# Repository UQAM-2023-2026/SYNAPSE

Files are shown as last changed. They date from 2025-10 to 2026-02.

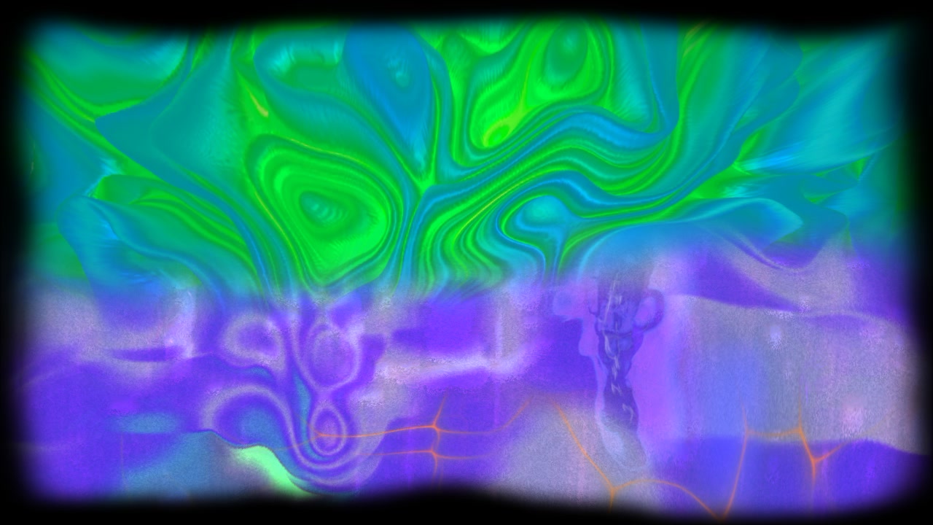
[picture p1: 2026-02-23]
src/TouchDesigner/Supra_Infra/Patch_global/infrasupra.jpeg

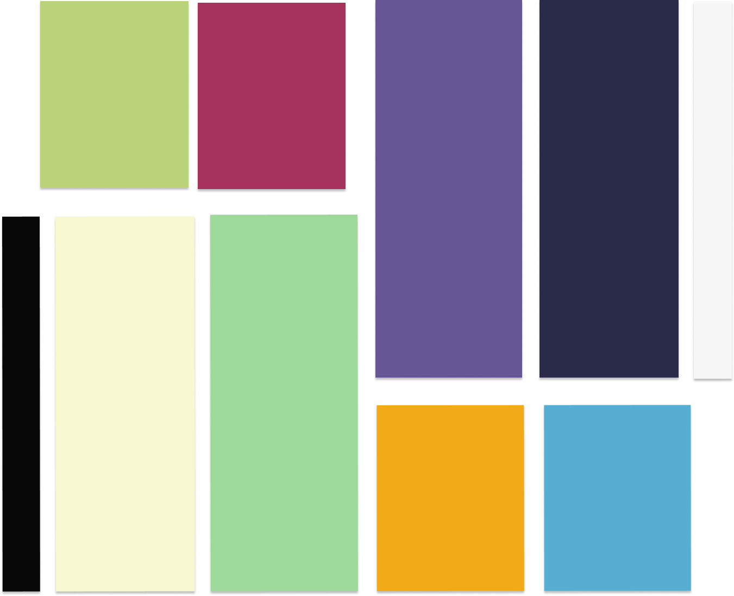
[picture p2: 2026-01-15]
src/TouchDesigner/Supra_Infra/Patch_global/medias/SUPRA/Supra/medias/palette_couleur.webp

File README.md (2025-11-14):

# SYN/APSE  
**Cohorte UQAM Médias Interactifs 2023-2026**

> _Explorer un écosystème du futur, où chaque geste humain nourrit un réseau vivant et lumineux._  

---

## 🌿 Introduction  

**SYN/APSE** est une installation interactive et collective qui invite le public à explorer un écosystème symbiotique inspiré des **réseaux mycorhiziens** — ces structures souterraines où racines et champignons échangent énergie et informations.  

L’œuvre se déploie en deux niveaux — **la Canopée (haut)** et **le Mycélium (bas)** — où les participant·es interagissent à l’aide d’**objets-racines** connectés.  
Chaque geste contribue à la **“communergie”** : un flux d’énergie collective qui illumine, transforme et fait croître un monde partagé.  

SYN/APSE explore les notions de **collaboration, équilibre écologique, espoir et futurité**, à travers une approche **low-tech, écologique et sensible** mêlant art, biologie, design et technologie interactive.

---

## 🧩 Concept et expérience  

### Gestes fondamentaux  
- **Récolter** — capter l’énergie à travers l’exploration et la présence.  
- **Transférer** — échanger cette énergie entre personnes ou systèmes.  
- **Déposer** — redonner à l’écosystème pour le nourrir collectivement.  

### Parcours utilisateur  
1. **Entrée dans la Canopée** : un espace lumineux et sonore où les racines réagissent à la présence.  
2. **Exploration et recharge** : en manipulant l’objet-racine, le public accumule de l’énergie via la lumière et le mouvement.  
3. **Connexion avec autrui** : deux participant·es peuvent rapprocher leurs racines pour amplifier leur énergie commune.  
4. **Dépôt dans un nœud** : l’énergie récoltée est transférée, activant un effet lumineux et sonore dans l’environnement.  
5. **Propagation** : le réseau s’illumine, des bourgeons apparaissent, les sons se multiplient — le monde se régénère.  

Chaque interaction révèle un cycle de **photosynthèse et d’échange**, symbolisant la coopération plutôt que la compétition.

---

## 💡 Technologies  

| Domaine | Outils et technologies |
|---|---|
| **Interactivité** | Capteurs infrarouges, transducteurs de surface, objets magnétiques connectés |
| **Lumière & projection** | Bandes LED, EL-Wire, projecteurs mapping |
| **Son** | Transducteurs sonores et ambiance évolutive |
| **Vision & capture** | Raspberry Pi, caméras et traitement d’image (OpenCV, scikit-image) |
| **IA & générativité** | Réseaux neuronaux pour formes visuelles et rétroaction sensorielle |
| **Logiciels** | TouchDesigner, Python, MaxMSP, Ableton Live |

> _L’installation combine art génératif, code créatif et dispositifs physiques réemployés, afin de limiter son empreinte écologique._

---

## ⚙️ Structure du dépôt  

```
SYN/APSE/
├─ docs/                      # Documentation projet
│  ├─ onboarding/             # Guides pour nouveaux arrivants
│  ├─ methodology/            # Méthodologie, décisions, RACI, etc.
│  └─ architecture/           # Diagrammes (Mermaid, PNG, PDF)
├─ src/                       # Code source (TouchDesigner, Python, etc.)
│  ├─ touchdesigner/
├─ assets/                    # Images, logos, polices
├─ hardware/                  # Schémas, BOM, STL, DXF, gerbers
├─ data/                      # Données (échantillons) — petites tailles
├─ scripts/                   # Outils dev/ops (build, export, sync)
├─ env/                       # Environnements
│  └─ environment.yml         # (renommer PF.yaml)
└─ README.md

```

---

## 🧠 Objectifs  

- Créer un **écosystème interactif** fondé sur la symbiose et l’équilibre collectif.  
- Favoriser une **expérience poétique et éducative** autour du vivant et du numérique.  
- Expérimenter un **design éthique** : matériaux réutilisés, inclusion, accessibilité.  
- Développer un **projet interdisciplinaire** où artistes, programmeur·euses et designers collaborent sur un même système vivant.  

---

## ♻️ Éthique et durabilité  

- **Réemploi** : priorité au matériel déjà existant.  
- **Accessibilité** : participation ouverte à tous.tes, sans barrière technologique.  
- **Équité et diversité** : représentation inclusive dans le concept et la production.  
- **Écologie** : conception à faible impact, matériaux biodégradables et recyclables.  

---

## 🧑‍🤝‍🧑 Équipe  

**Cohorte Médias Interactifs 2023-2026 – UQAM**  

---

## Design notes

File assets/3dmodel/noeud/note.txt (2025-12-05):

les trou sur le coté sont pour un des led et l'autre pour le recepteur. lui du mileu et pour le support. peuttre devoir le grossir avec la drille blanc sur le grandeur tu trou au milieur mais pour les autre c'Est 3 cm par 3 cm

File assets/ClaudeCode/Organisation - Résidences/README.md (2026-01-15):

# Gestion des Résidences de Création

Application web pour gérer les disponibilités, planifier les résidences de création et faciliter l'organisation à l'école.

## 🚀 Démarrage rapide

### Option 1: Serveur Python (Recommandé pour accès réseau)

```bash
python3 serveur.py
```

Le navigateur s'ouvrira automatiquement à `http://localhost:8000/residences.html`

**Pour accéder depuis d'autres ordinateurs sur le même réseau:**
1. Trouvez l'adresse IP de votre ordinateur:
   - Mac/Linux: `ifconfig` ou `ip addr`
   - Windows: `ipconfig`
2. Les autres peuvent accéder à `http://[VOTRE-IP]:8000/residences.html`

### Option 2: Ouvrir directement le fichier

Double-cliquez simplement sur `residences.html` - ça fonctionne hors ligne!

## 📋 Fonctionnalités

### 1. Tableau de bord
- Voir qui est présent aujourd'hui
- Afficher les projets sur lesquels chacun travaille
- Statistiques rapides

### 2. Disponibilités
- Chaque personne peut marquer ses périodes de disponibilité
- Ajouter des notes et des plages horaires spécifiques
- Voir toutes ses disponibilités enregistrées

### 3. Calendrier
- Vue hebdomadaire des disponibilités
- Voir rapidement qui est disponible chaque jour
- Navigation facile entre les semaines

### 4. Résidences
- Planifier une résidence pour une date spécifique
- Sélectionner les personnes qui devraient venir
- Définir un ordre de priorité (qui est prioritaire pour venir)
- Voir toutes les résidences planifiées

### 5. Gestion des personnes
- Ajouter/supprimer des personnes
- Exporter toutes les données en JSON
- Importer des données sauvegardées

## 💾 Sauvegarde des données

Les données sont automatiquement sauvegardées dans le **localStorage** du navigateur.

⚠️ **Important:** Les données sont stockées localement sur chaque ordinateur/navigateur. Pour partager les données entre plusieurs appareils:

1. Utilisez l'option **"Exporter les données"** dans l'onglet "Personnes"
2. Partagez le fichier JSON
3. Importez-le sur les autres appareils

### Pour une utilisation collaborative

Si vous voulez que tout le monde travaille sur les mêmes données en temps réel, vous avez deux options:

#### Option A: Ordinateur partagé à l'école
- Installez l'application sur un ordinateur fixe
- Tout le monde l'utilise sur place

#### Option B: Serveur accessible en ligne
- Hébergez le fichier sur un serveur web
- Utilisez Tailscale, ngrok ou un hébergement cloud
- Tout le monde peut y accéder à distance

## 🎨 Personnalisation

Le fichier `residences.html` est autonome - tout le CSS et JavaScript est inclus. Vous pouvez:
- Modifier les couleurs dans la section `<style>`
- Ajouter des champs personnalisés dans le JavaScript
- Adapter l'interface à vos besoins

## 🔧 Workflow recommandé

1. **En début de session:**
   - Chaque personne marque ses disponibilités dans l'onglet "Disponibilités"

2. **Planification:**
   - L'organisateur va dans "Résidences"
   - Crée une résidence pour une date
   - Sélectionne les personnes (en ordre de priorité)

3. **Jour de résidence:**
   - Ouvrir le "Tableau de bord"
   - Sélectionner la date du jour
   - Voir qui doit venir et sur quoi chacun travaille
   - Mettre à jour les projets au besoin

4. **Sauvegarde régulière:**
   - Exporter les données régulièrement
   - Garder une copie de backup

## 📱 Utilisation mobile

L'interface est responsive et fonctionne sur mobile/tablette!

## 🆘 Support

Pour des questions ou des améliorations, modifiez directement le code HTML ou contactez le développeur.

## 📊 Liste des personnes initiales

L'application est pré-configurée avec les 28 personnes de votre fichier Excel:

Sasha, Dom, Rachel, Florence, Tom, Aldric, Émilie, Maria, Maude, Noum, Med, Thierry, No, JC, Justin, Raton, Anthonny, Sarah, Ugo, Clément, Max, Mery, Laura, Emmanuel, Alexandre, Katianna, Louis-David, Léa

Vous pouvez ajouter ou supprimer des personnes dans l'onglet "Personnes".

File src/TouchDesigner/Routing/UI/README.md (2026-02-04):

# SYNAPSE OSC UI Monitor

Interface web pour visualiser en temps réel les données OSC streamées sur le port 6970.

## Installation

1. Installer les dépendances Python:
```bash
pip install -r requirements.txt
```

## Utilisation

1. Démarrer le serveur OSC/WebSocket:
```bash
python3 osc_server.py
```

2. Ouvrir l'interface web dans un navigateur:
```bash
python3 -m http.server 8000
```

3. Naviguer vers: http://10.0.2.245:8000

## Architecture

- **osc_server.py**: Écoute les messages OSC sur le port 6970 et les redistribue via WebSocket
- **index.html**: Interface web qui affiche les messages en temps réel
- Port OSC: 6970 (local)
- Port WebSocket: 8765
- Port HTTP: 8000

## Fonctionnalités

- Visualisation en temps réel des messages OSC
- Statistiques (messages/sec, total, adresses uniques)
- Pause/Resume du flux
- Export des messages en JSON
- Historique des 1000 derniers messages
- Interface moderne avec gradient et animations

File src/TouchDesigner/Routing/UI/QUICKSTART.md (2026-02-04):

# SYNAPSE Dashboard - Quick Start

## 🚀 Launch en Un Click (Méthode Recommandée)

### Option 1 : Double-click sur macOS
Double-cliquez sur le fichier :
```
LAUNCH_SYNAPSE.command
```

### Option 2 : Via Terminal
```bash
cd /Users/cexiistudiom4max/Desktop/SYNAPSE/src/TouchDesigner/Routing/UI
./launch.py
# ou
python3 launch.py
```

**Le launcher fait automatiquement :**
- ✅ Démarre le serveur OSC/WebSocket (port 6970 + 8765)
- ✅ Démarre le serveur HTTP (port 8000)
- ✅ Ouvre le dashboard dans votre navigateur
- ✅ Gère proprement l'arrêt avec Ctrl+C

## 🛑 Arrêt

Appuyez sur `Ctrl+C` dans le terminal pour arrêter **tous** les services proprement.

## 📊 URLs d'Accès

- **Dashboard** : http://localhost:8000/dashboard.html
- **WebSocket** : ws://localhost:8765
- **OSC Port** : 6970 (UDP)

## 🔧 Configuration TouchDesigner

Dans TouchDesigner, configurez votre **OSC Out CHOP** :
- **Network Address** : `127.0.0.1` (local) ou `10.0.2.245` (réseau)
- **Network Port** : `6970`
- **Protocol** : `UDP`
- **Active** : `On`

## 📱 Résolution

Le dashboard est optimisé pour **1280×720 pixels** (sans scroll).

---

## 🧪 Méthode Manuelle (Alternative)

Si vous préférez lancer les composants séparément :

**Terminal 1** - Serveur OSC/WebSocket :
```bash
python3 debug_server.py
```

**Terminal 2** - Serveur HTTP :
```bash
python3 -m http.server 8000
```

**Navigateur** - Ouvrir manuellement :
```
http://localhost:8000/dashboard.html
```

---

## ⚠️ Troubleshooting

### Port 8000 déjà utilisé
```bash
# Trouver le processus
lsof -i :8000

# Tuer le processus
kill -9 <PID>
```

### Port 6970 (OSC) déjà utilisé
```bash
# Trouver le processus
lsof -i :6970

# Tuer le processus
kill -9 <PID>
```

### Serveur ne démarre pas
Vérifiez que les dépendances sont installées :
```bash
pip install -r requirements.txt
```

### TouchDesigner n'envoie rien
- Vérifier que le OSC Out CHOP est **Active**
- Vérifier le port (doit être `6970`)
- Vérifier l'adresse IP
- Regarder les logs dans TouchDesigner

### L'interface web ne se connecte pas
- Vérifier que le serveur OSC/WebSocket tourne
- Ouvrir la console du navigateur (F12) pour voir les erreurs
- Vérifier le status dans le header (doit être "Connected")

### Dashboard ne s'affiche pas correctement
- Utiliser un navigateur moderne (Chrome, Firefox, Safari récent)
- Vérifier la résolution de la fenêtre (1280×720 recommandé)
- Désactiver les extensions de navigateur qui pourraient interférer

---

## 📁 Structure des Fichiers

```
UI/
├── LAUNCH_SYNAPSE.command     ← Double-click pour démarrer (macOS)
├── launch.py                  ← Launcher Python intelligent
├── debug_server.py            ← Serveur OSC/WebSocket
├── dashboard.html             ← Interface web (1280×720)
├── requirements.txt           ← Dépendances Python
├── QUICKSTART.md              ← Guide de démarrage
├── README.md                  ← Documentation
└── TOUCHDESIGNER_CONFIG.md    ← Configuration TouchDesigner
```

## 🎯 Workflow Recommandé

1. **Double-click** sur `LAUNCH_SYNAPSE.command`
2. Attendre que le navigateur s'ouvre automatiquement
3. Vérifier que le status est "Connected" (LED verte)
4. Lancer TouchDesigner et configurer OSC Out
5. Les données devraient apparaître en temps réel
6. `Ctrl+C` dans le terminal pour tout arrêter

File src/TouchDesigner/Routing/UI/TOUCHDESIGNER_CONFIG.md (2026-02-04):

# Configuration TouchDesigner pour OSC

## Configuration OSC Out dans TouchDesigner

Pour envoyer des données vers le moniteur UI, configurez votre OSC Out CHOP:

1. **Network Address**: `10.0.2.245`
2. **Network Port**: `6970`
3. **Protocol**: `UDP`

## Exemple de configuration

```
OSC Out CHOP:
- Active: On
- Network Address: 10.0.2.245
- Network Port: 6970
- Protocol: UDP
- OSC Address: /synapse/[nom_du_canal]
```

## Test depuis TouchDesigner

Vous pouvez tester en créant un simple setup:

1. Créer un **Constant CHOP** avec quelques canaux
2. Créer un **OSC Out CHOP**
3. Connecter le Constant au OSC Out
4. Configurer l'OSC Out:
   - Address: 10.0.2.245
   - Port: 6970
   - Vérifier que "Active" est coché

## Vérification des ports

Si vous utilisez déjà le port 6970 pour autre chose dans TouchDesigner:

### Option 1: Changer le port du moniteur
Éditez `osc_server.py` ligne 91:
```python
osc_port = 6970  # Changer pour un autre port
```

### Option 2: Changer le port dans TouchDesigner
Modifiez simplement le port dans votre OSC Out CHOP

## Debugging

1. Vérifier que le serveur OSC est lancé:
```bash
lsof -i :6970
```

2. Envoyer des messages de test:
```bash
python3 test_osc.py
```

3. Vérifier les logs du serveur dans le terminal où `osc_server.py` tourne

## Format des messages OSC

Le serveur accepte tous les formats de messages OSC:
- `/chemin/vers/data` [valeur1, valeur2, ...]
- Supporte: float, int, string, bool

Exemple:
- `/synapse/position/x 0.5`
- `/synapse/velocity 1.2 3.4 5.6`
- `/synapse/status "active"`

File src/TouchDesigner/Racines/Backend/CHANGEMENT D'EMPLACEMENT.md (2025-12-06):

La patch de backend a bougé dans src/Touchdesigner/Routing/Backend

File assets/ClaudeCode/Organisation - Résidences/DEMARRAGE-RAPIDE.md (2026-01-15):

# 🚀 Démarrage Rapide - Résidences EDM3003

## Étape 1: Ouvrir l'application

```bash
python3 serveur.py
```

Ou double-cliquez sur `residences.html`

## Étape 2: Importer l'horaire EDM3003

1. Ouvrez `import-horaire.html` dans votre navigateur
2. Cliquez sur **"Importer l'horaire dans l'application"**
3. Cliquez sur **"Ouvrir l'application"**

✅ Toutes les sessions PM/SOIR sont maintenant importées avec leurs types d'activités!

## Étape 3: Marquer les disponibilités

1. Allez dans l'onglet **"Disponibilités"**
2. Cliquez sur votre nom
3. Sélectionnez vos dates de disponibilité
4. Cliquez sur **"Enregistrer la disponibilité"**

## Étape 4: Assigner les personnes aux résidences

1. Allez dans l'onglet **"Résidences"**
2. Trouvez une résidence importée (elles ont une barre colorée à gauche selon le type)
3. Cliquez sur **"Éditer"** *(à implémenter)* ou créez une nouvelle résidence pour une date existante
4. Sélectionnez les personnes qui doivent venir
5. Organisez-les par priorité avec les flèches ↑↓

## Étape 5: Voir qui est là aujourd'hui

1. Allez dans l'onglet **"Tableau de bord"**
2. Sélectionnez la date du jour
3. Voyez toutes les sessions (PM/SOIR) avec:
   - Le type d'activité coloré
   - Les personnes attendues par priorité
   - Les projets sur lesquels chacun travaille

## Types d'activités et couleurs

- 🔵 **Planification** - Bleu
- 🟢 **Résidence de création** - Vert
- 🟡 **Test** - Jaune
- 🔴 **Revue** - Rouge
- 🟣 **Montage** - Violet
- 🟠 **Générale** - Orange
- 🎀 **Lancement** - Rose
- ⚫ **Mise en place / Démontage** - Gris
- 🔵 **Présentation** - Cyan
- 🟢 **Post-mortem** - Teal

## Sessions PM vs SOIR

Les résidences importées ont automatiquement:
- **PM**: 13h00 - 17h00
- **SOIR**: 18h00 - 22h00

Vous pouvez ajuster les heures au besoin.

## Workflow recommandé

### Pour les étudiants:
1. Marquez vos disponibilités à l'avance
2. Consultez le tableau de bord pour voir quand vous êtes attendus
3. Mettez à jour votre projet du jour

### Pour l'organisateur:
1. Importez l'horaire au début de la session
2. Assignez les personnes aux résidences selon les disponibilités
3. Utilisez le système de priorités pour indiquer qui doit absolument venir
4. Consultez le calendrier pour une vue d'ensemble hebdomadaire

## Astuces

- 💾 **Les données sont sauvegardées automatiquement** dans le navigateur
- 📤 **Exportez régulièrement** via l'onglet "Personnes"
- 🎨 **Les couleurs indiquent le type d'activité** - facile de distinguer un test d'une résidence
- 📱 **Fonctionne sur mobile** - consultez le tableau de bord depuis votre téléphone
- 🔍 **Utilisez la recherche** pour trouver rapidement une personne

## Accès réseau (pour toute l'équipe)

Si vous voulez que tout le monde puisse accéder:

1. Lancez le serveur: `python3 serveur.py`
2. Trouvez votre adresse IP:
   - Mac: `ifconfig | grep "inet " | grep -v 127.0.0.1`
   - Linux: `ip addr show | grep "inet " | grep -v 127.0.0.1`
   - Windows: `ipconfig`
3. Les autres accèdent via: `http://[VOTRE-IP]:8000/residences.html`

## Besoin d'aide?

- Consultez le `README.md` pour plus de détails
- Les fichiers sont dans: `/Organisation - Résidences/`
- Vos données sont dans le localStorage du navigateur

## Dates importantes EDM3003

- **12 janv** - Mise en place
- **14 janv** - PLANIFICATION S5
- **26 janv** - TEST INTÉRIEUR 1
- **28 janv** - REVUE S5
- **2 fév** - PLANIFICATION S6
- **11 fév** - TEST INTÉRIEUR 2
- **16 fév** - REVUE S6 (avec public invité!)
- **18 fév** - RÉTRO S6 / PLANIFICATION S7
- **23-25 fév** - Montage Synapse
- **25 fév** - Générale Synapse
- **26 fév - 1 mars** - Lancement Synapse
- **2-5 mars** - Démontage et rangement
- **16 mars** - Post-mortem

Bon courage avec vos résidences! 🎭✨

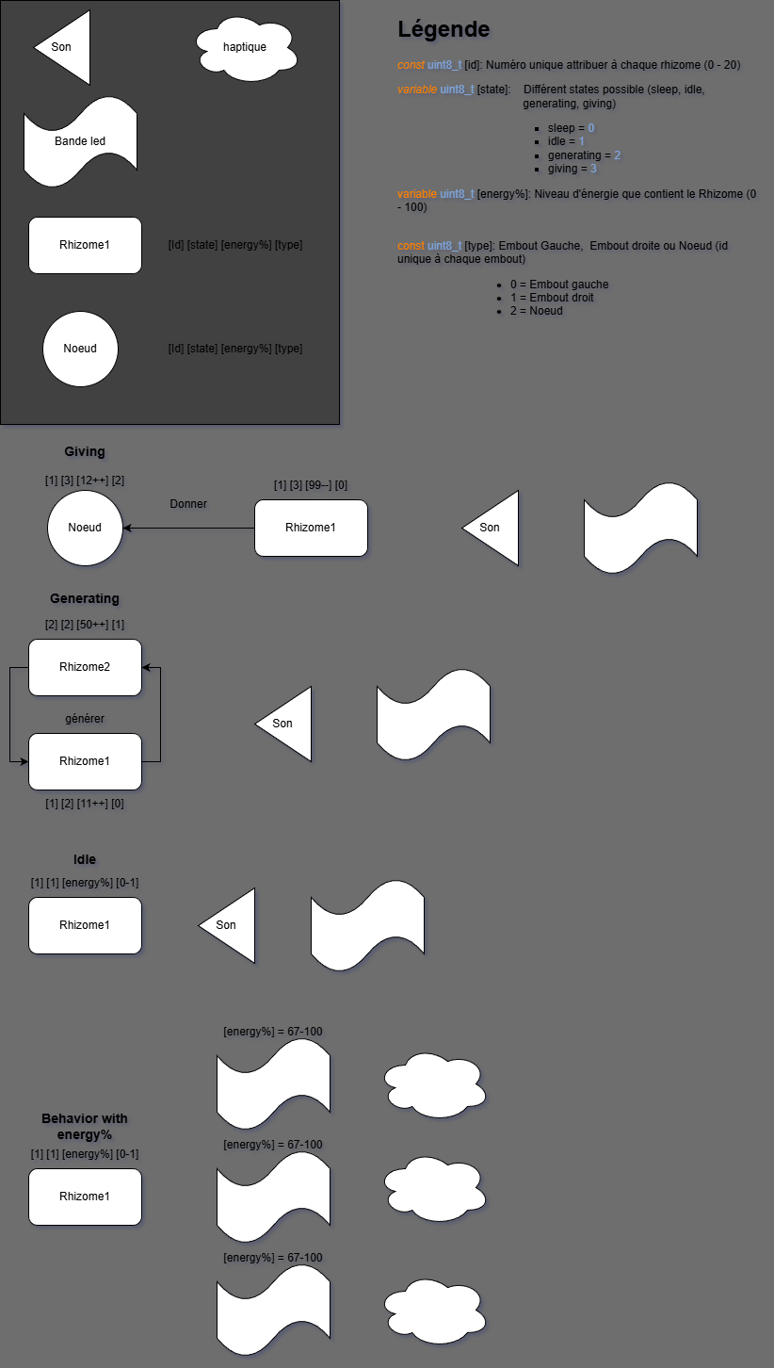
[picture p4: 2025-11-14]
src/schemas/rhizome/KiCad/parcoursEnergie.drawio.png

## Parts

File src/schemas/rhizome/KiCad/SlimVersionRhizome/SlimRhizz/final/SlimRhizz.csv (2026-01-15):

Reference | Value | Footprint
C1,C2,C3 | 1000uf | Capacitor_SMD:CP_Elec_10x10.5
C4,C5 | 100uf | Capacitor_SMD:CP_Elec_6.3x5.4
D1 | PWR | LED_SMD:LED_0402_1005Metric
D2 | HBT | LED_SMD:LED_0402_1005Metric
D3 | L-Connect | LED_SMD:LED_0402_1005Metric
D4 | R-Connect | LED_SMD:LED_0402_1005Metric
J1 | POWER_IN | Connector_JST:JST_XH_B2B-XH-A_1x02_P2.50mm_Vertical
J2 | WS2812_Tip1 | Connector_JST:JST_XH_B3B-XH-A_1x03_P2.50mm_Vertical
J3 | WS2812_Tip2 | Connector_JST:JST_XH_B3B-XH-A_1x03_P2.50mm_Vertical
J4 | APA102_Strip | Connector_JST:JST_XH_B4B-XH-A_1x04_P2.50mm_Vertical
J5 | Haptic_DRV1 | Connector_JST:JST_XH_B4B-XH-A_1x04_P2.50mm_Vertical
J6 | Haptic_DRV2 | Connector_JST:JST_XH_B4B-XH-A_1x04_P2.50mm_Vertical
J7 | Pogo_Male | Connector_JST:JST_XH_B5B-XH-A_1x05_P2.50mm_Vertical
J8 | Pogo_Female | Connector_JST:JST_XH_B5B-XH-A_1x05_P2.50mm_Vertical
R1,R2,R3,R4 | 220 | Resistor_SMD:R_0805_2012Metric
R5 | 1000 | Resistor_SMD:R_0402_1005Metric
R6,R7,R8 | 330 | Resistor_SMD:R_0402_1005Metric

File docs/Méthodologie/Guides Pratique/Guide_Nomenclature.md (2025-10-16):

# Conventions de Nommage (Nomenclature)

La cohérence dans les noms de fichiers est essentielle pour faciliter le travail d’équipe et la maintenance du projet **Mycorhize**.  
Ce guide résume les conventions de nommage définies pour ce projet, en s’alignant sur son vocabulaire thématique (*rhizome*, *nœud*, *supra*, *infra*, *dépôt*, *récolte*, etc.) et sur le ton clair et concis des autres guides d’onboarding.  
L’objectif est de rendre les fichiers aisément identifiables et **rapidement scannables** par tout nouvel arrivant.

---

## Principes Généraux

- **Clarté et concision :** Choisissez des noms de fichiers courts mais explicites.  
  Évitez les termes génériques ou les abréviations obscures.  
  Chaque nom doit indiquer clairement le contenu ou le rôle du fichier (ex. préférez `schema_reseau.png` à `image1.png`).

- **Vocabulaire du projet :** Réutilisez les termes propres à Mycorhize pour refléter la structure du projet.  
  Par exemple :
  - le module central utilise le préfixe **Rhizome** ;
  - les fichiers liés aux capteurs de terrain commencent par **Noeud** ;
  - les éléments de la zone supérieure utilisent **Supra** ;
  - ceux de la zone inférieure utilisent **Infra**.  
  Cette métaphore commune facilite la compréhension du rôle de chaque fichier au sein du « mycélium » du projet.

- **Séparateurs et caractères spéciaux :**  
  N’utilisez **pas d’espaces** ni de caractères accentués dans les noms de fichiers.  
  Remplacez les espaces par des tirets bas `_` et retirez les accents (`Supra` au lieu de `Suprâ`).  
  Évitez les caractères spéciaux et les majuscules dans les extensions.

- **Préfixes par catégorie :**  
  Adoptez un système de **préfixes** pour regrouper les fichiers par type ou fonction :  
  `Rapport_`, `Noeud_`, `Infra_`, `Supra_`, `Rhizome_`, etc.  
  Cela facilite le tri alphabétique et la recherche rapide dans le dépôt.

- **Informations en suffixe :**  
  Ajoutez des détails en fin de nom pour distinguer les versions ou contextes :  
  `_v1`, `_v2`, ou une date au format ISO `AAAA-MM-JJ`.

- **Extensions standard :**  
  Conservez les extensions appropriées (`.pdf`, `.ino`, `.png`, `.wav`, `.mp4`, etc.)  
  sans les répéter dans le nom.

---

## Conventions par Type de Fichier

### Documents PDF (Rapports, Guides, etc.)

- **Nom descriptif + type de doc :**  
  Commencez par un préfixe comme `Rapport_`, `Guide_`, `CompteRendu_`, suivi d’un titre clair.
- **Version et date :**  
  Utilisez un suffixe pour distinguer les versions (`_v2`) ou les dates.
- **Exemples :**
  - `Rapport_Mycorhize_v1.pdf`
  - `Guide_Installation_2025-05.pdf`
  - `Doc_Budget_Supra_2025.pdf`

---

### Code Arduino (Sketches des nœuds et du rhizome)

- **Préfixe du système :**  
  Utilisez **Noeud** pour les capteurs/dispositifs et **Rhizome** pour le module central.  
- **Descriptif fonctionnel :**  
  Ajoutez ensuite la fonction du code (capteurs, transfert, communication…).
- **Exemples :**
  - `Noeud7_CapteursInfra.ino`
  - `Rhizome_TransfertEnergie.ino`
  - `Noeud_Supra_LEDsync_v2.ino`

---

### Fichiers Visuels (Images, Schémas)

- **Contexte et contenu :**  
  Indiquez le module ou la zone (`Supra`, `Infra`, `Noeud`, `Rhizome`) et le contenu (`schema`, `prototype`, `rendu`…).
- **Date ou numéro de version :**  
  Ajoutez une date (`2025-10-16`) ou une version (`v2`).
- **Exemples :**
  - `Infra_Mapping_v1.png`
  - `Schema_Rhizome_v2.svg`
  - `Supra_Installation_2025-10-16.jpg`

---

### Fichiers Audio

- **Source et contexte :**  
  Utilisez un préfixe clair (`Infra`, `Supra`, `NoeudX`, etc.) et un mot-clé décrivant le son.
- **Date d’enregistrement :**  
  Ajoutez la date si plusieurs versions existent.
- **Exemples :**
  - `Audio_Supra_Ambiance_2025-10-16.wav`
  - `Audio_Noed3_Recolte_v1.mp3`
  - `Audio_Infra_Pulse_v2.wav`

---

### Fichiers Vidéo

- **Sujet et emplacement :**  
  Commencez par la zone ou le module (`Infra`, `Supra`, `Rhizome`).
- **Date et séquence :**  
  Ajoutez la date (`AAAA-MM-JJ`) ou un numéro de séquence.
- **Exemples :**
  - `Supra_Timelapse_2025-10-16.mp4`
  - `Infra_Recolte_v2.mp4`
  - `Rhizome_Demo_2025-05-02.mov`

---

## Tableau Récapitulatif des Préfixes/Suffixes

| **Type de fichier** | **Préfixes recommandés** | **Suffixes** |
|---|---|---|
| **Documents PDF** | `Rapport_`, `Guide_`, `Doc_` | `_vX` / date (`AAAA-MM-JJ`) |
| **Code Arduino (.ino)** | `NoeudX_`, `Rhizome_` | *(extension uniquement)* |
| **Visuels (Images)** | `Supra_`, `Infra_`, `NoeudX_`, `Rhizome_` | `_vX` / date (`AAAA-MM-JJ`) |
| **Audio (Sons)** | `Audio_Supra_`, `Audio_Infra_`, `Audio_NoeudX_` | `_vX` / date (`AAAA-MM-JJ`) |
| **Vidéo** | `Supra_`, `Infra_`, `Rhizome_` | `_vX` / date (`AAAA-MM-JJ`) |

---

## Bonnes Pratiques Résumées

✅ Utilisez toujours **des noms en minuscules** et **sans accents**.  
✅ Séparez les mots avec `_`.  
✅ Employez le **vocabulaire du projet** (`rhizome`, `infra`, `supra`, `noeud`).  
✅ Ajoutez une **version ou une date** pour assurer le suivi.  
✅ Soyez **cohérent·e** — le respect collectif de cette nomenclature garantit un dépôt clair et durable.

---

*Fichier : `/docs/onboarding/nomenclature.md`*  
*Version : 1.0 — dernière mise à jour : 2025-10-16*

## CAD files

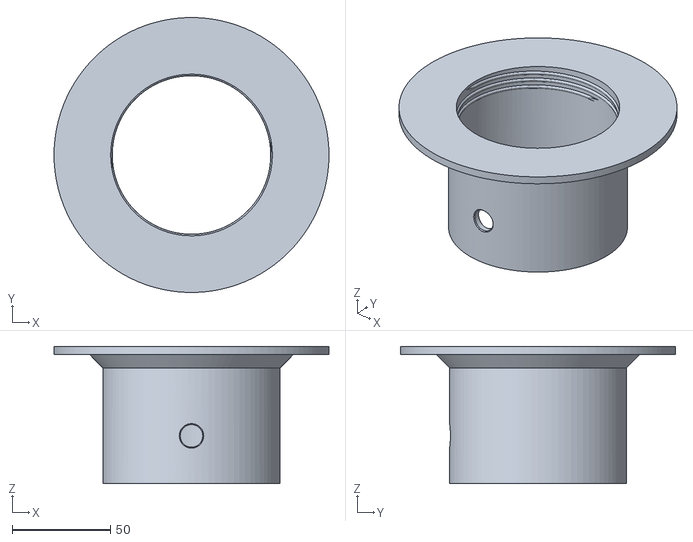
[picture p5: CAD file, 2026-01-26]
assets/3dmodel/noeud/connecteur/Middle_noeu.stl
140.0 x 139.9 x 69.8

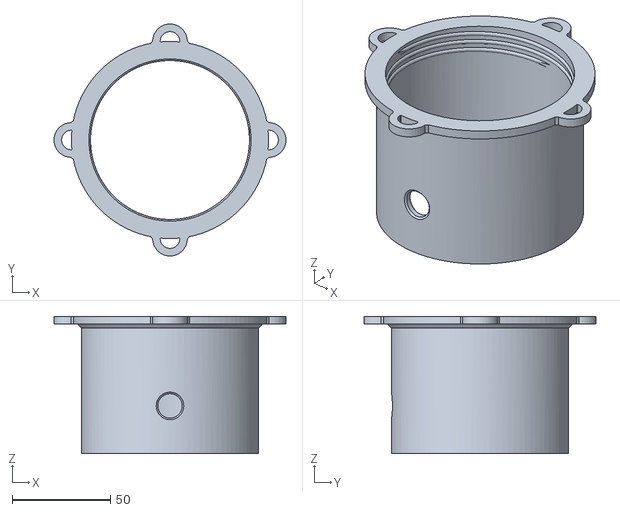
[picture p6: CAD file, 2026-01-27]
assets/3dmodel/noeud/connecteur2/MIDDLE_Connecteur_noeud_v2.stl
117.8 x 117.8 x 69.8

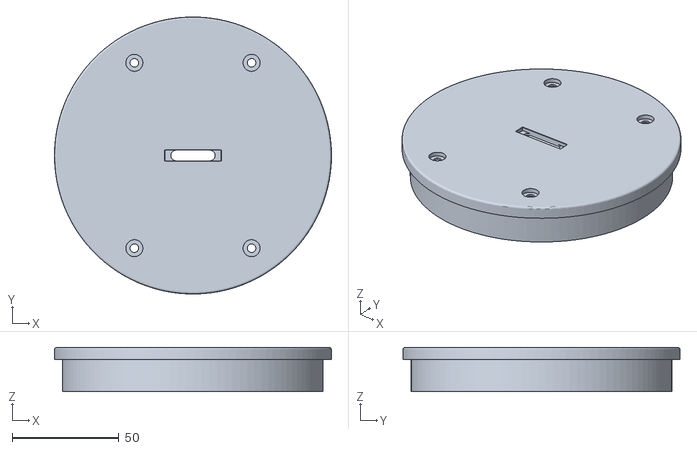
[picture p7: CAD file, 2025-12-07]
assets/3dmodel/noeud/Connecteur_Noeud.stl
130.0 x 130.0 x 20.7

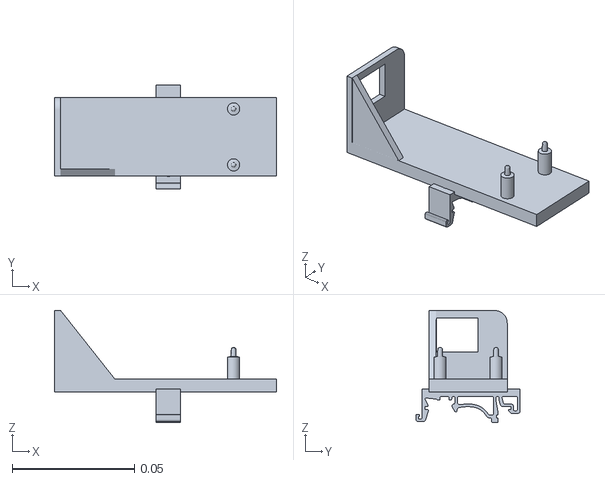
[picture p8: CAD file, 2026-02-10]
assets/3dmodel/noeud/ESPCASE/4espcase.stl
0.0907 x 0.0426 x 0.0458

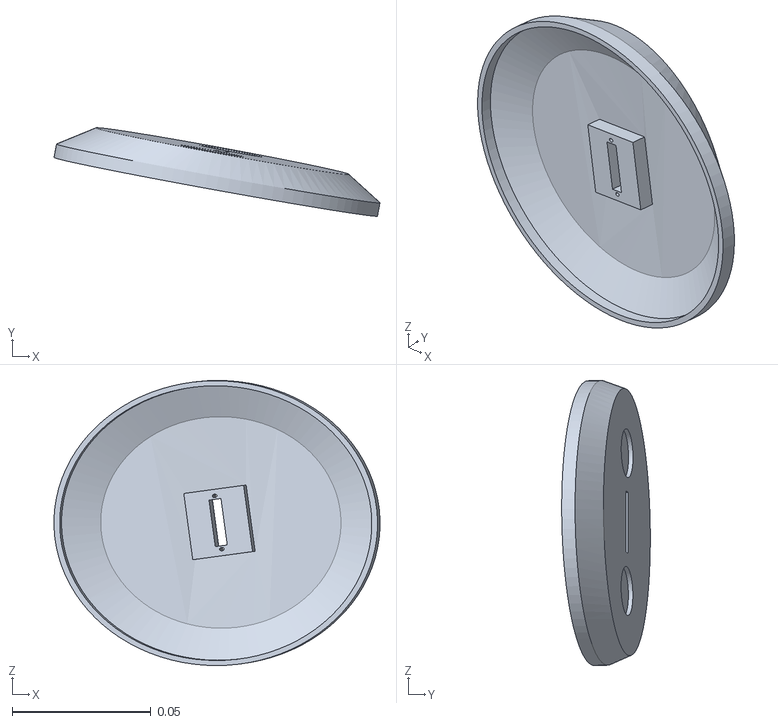
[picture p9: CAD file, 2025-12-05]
assets/3dmodel/obgj/recepeteur- Copie4.obj
0.117 x 0.0319 x 0.103

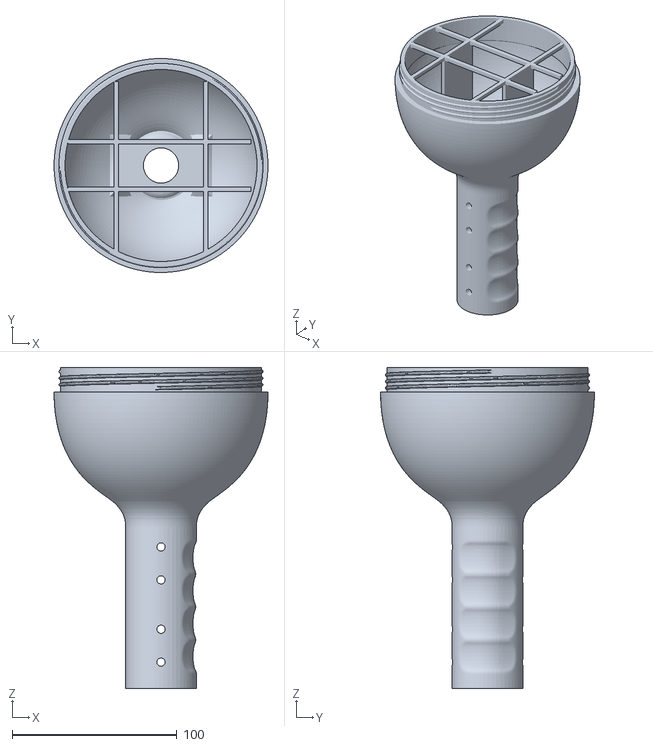
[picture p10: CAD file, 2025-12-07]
assets/3dmodel/Rhizome/v2/Female_plug_RHYZOMME_v2.stl
130.0 x 130.0 x 195.0

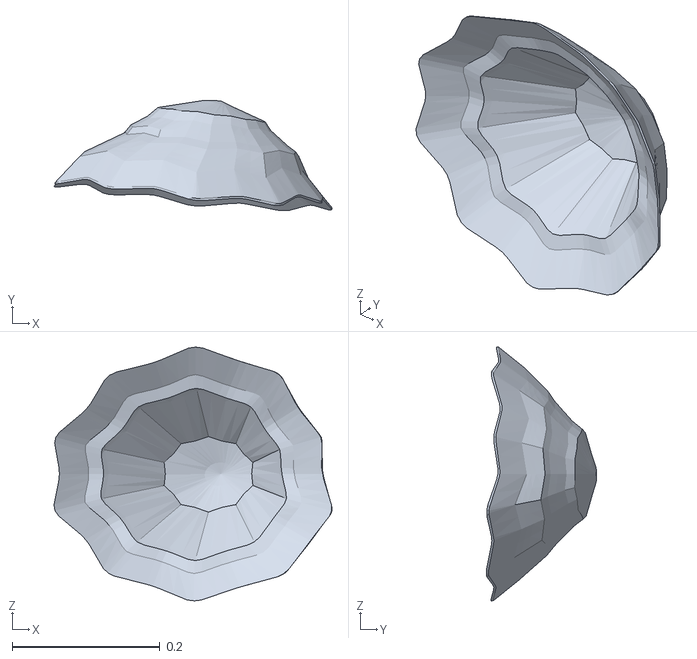
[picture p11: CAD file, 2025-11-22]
assets/3dmodel/testing/Champignon.obj
0.376 x 0.149 x 0.343

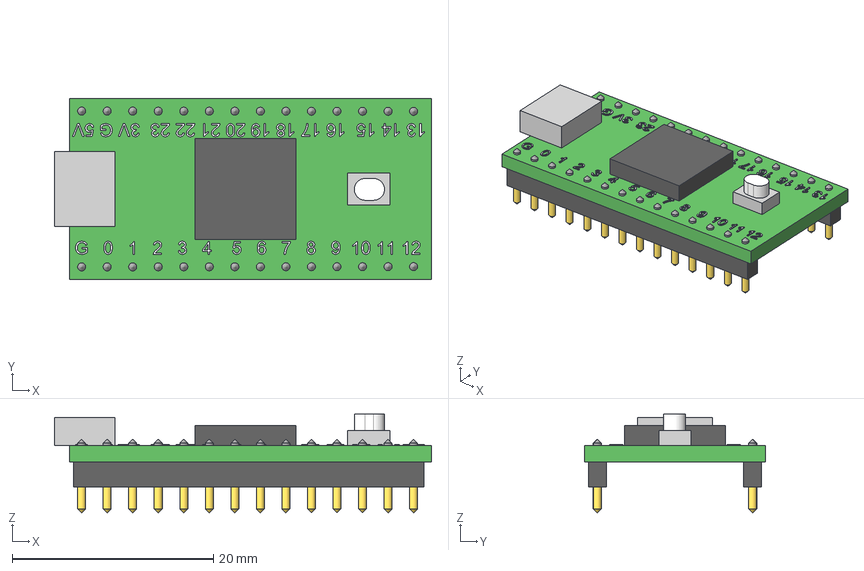
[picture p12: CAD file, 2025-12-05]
src/schemas/rhizome/KiCad/SlimVersionRhizome/SlimRhizz/lib_rhizome/3d_models/Teensy_4.0r0.step
37.5 x 18.0 x 9.80 mm
Teensy_4.0r001

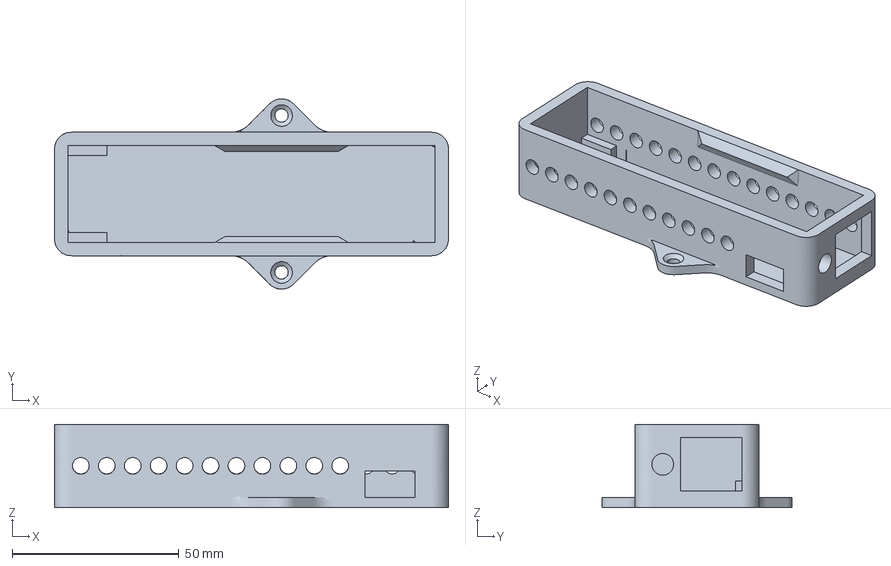
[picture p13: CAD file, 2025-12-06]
assets/3dmodel/noeud/CasePourESP32-POE-ISO.3mf
118.0 x 57.0 x 25.0 mm

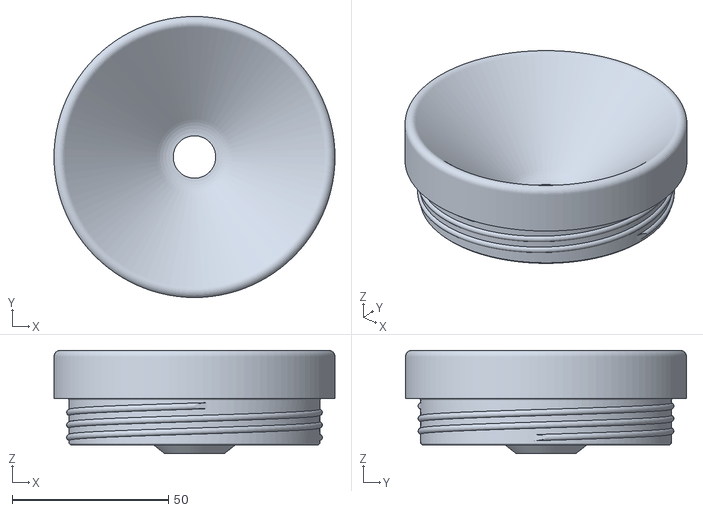
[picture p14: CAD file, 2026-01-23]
assets/3dmodel/noeud/connecteur2/Connecteur_noeu.stl
90.0 x 90.0 x 33.1

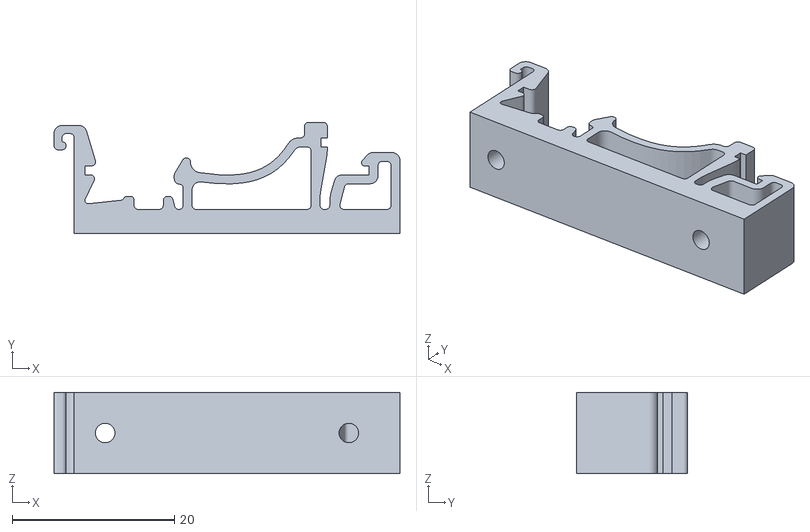
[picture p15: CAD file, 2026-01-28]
assets/3dmodel/noeud/ESPCASE/DIN_holder.stl
42.6 x 13.7 x 10.0

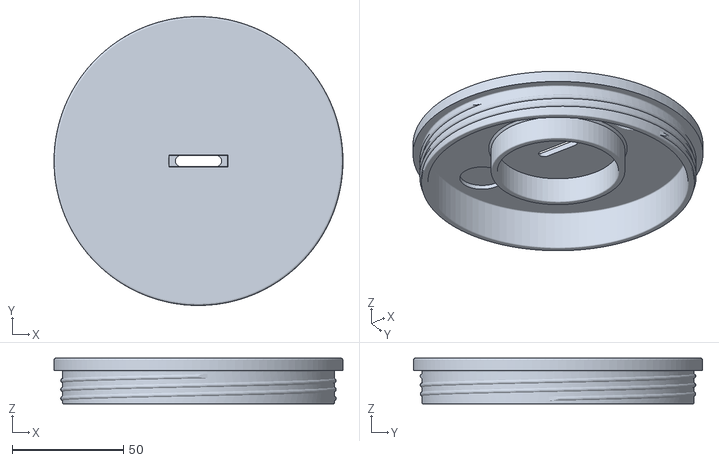
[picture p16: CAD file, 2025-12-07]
assets/3dmodel/Rhizome/v2/Connecteur_rhyzome_v2.stl
130.0 x 130.0 x 20.7

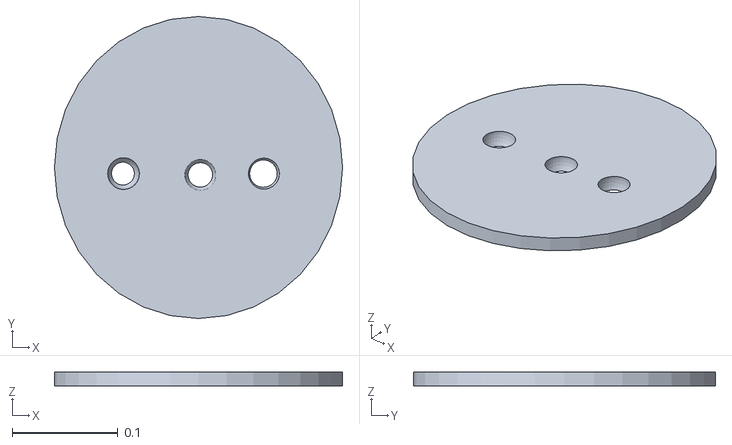
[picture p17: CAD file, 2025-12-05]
assets/3dmodel/noeud/basse- Copie6.stl
0.272 x 0.285 x 0.0134

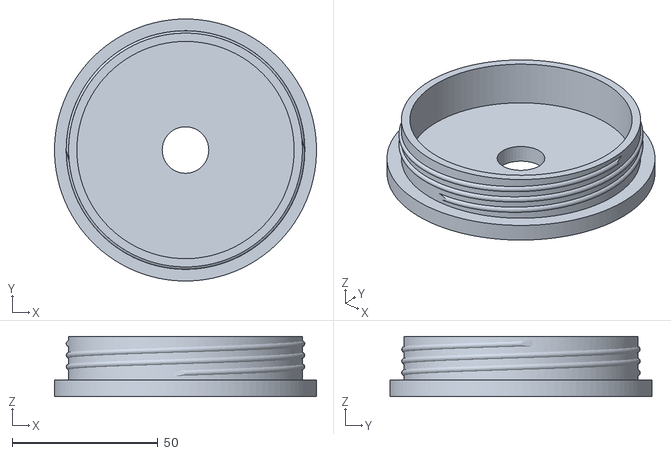
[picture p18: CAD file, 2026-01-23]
assets/3dmodel/noeud/connecteur2/BAse_noeu.stl
90.0 x 90.0 x 20.7

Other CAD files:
assets/3dmodel/noeud/ESPCASE/espcase4.3mf
assets/3dmodel/Rhizome/v2/Middle_V2.stl
assets/3dmodel/noeud/ESPCASE/espbonsens.stl
assets/3dmodel/noeud/ESPCASE/espcase2.stl
assets/3dmodel/Rhizome/v1/Connecteur.stl
assets/3dmodel/Rhizome/v1/Middle.stl
assets/3dmodel/Rhizome/v1/Rhyzome_femelle.stl
assets/3dmodel/Rhizome/v1/Rhyzome_male.stl
assets/3dmodel/VISE.blend
assets/3dmodel/noeud/ESPCASE/4espcase.blend
assets/3dmodel/noeud/ESPCASE/espcase.blend
assets/3dmodel/noeud/ESPCASE/espcase1.stl
assets/3dmodel/noeud/ESPCASE/espcase3.stl
assets/3dmodel/noeud/ESPCASE/espcase4.stl
assets/3dmodel/supportled.blend
assets/3dmodel/testing/CHAMPIGNONblendfinalsanrouge - Copie4.blend
assets/3dmodel/v2- Copie6.blend

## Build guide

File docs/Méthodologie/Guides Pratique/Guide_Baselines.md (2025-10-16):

# Baselines
*Ici, on parle des outils communs qui se retrouveront à travers le projet*

## Outils
### Communication
1. **Discord**
2. **Teams**

### Versionning
1. **Github**
2. *Stockage*

### Workflows
1. **TouchDesigner**
2. **Ableton**
3. **Arduino IDE**
4. **Fritzing**
5. **Diagram.net**
6. **Github Desktop**
7. **Resolume**
9. **DaVinci**
10. **Adobe Suite**

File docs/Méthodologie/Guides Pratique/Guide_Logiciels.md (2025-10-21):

# Guide des versions logicielles
*Ici se trouve les logiciels dont nous avons une ou des licences perpétuelles et leurs versions.*
## TouchDesigner 
Stable **2023.12480**

## Ableton
**Live Suite 11**

## MaxMSP
**Max9**

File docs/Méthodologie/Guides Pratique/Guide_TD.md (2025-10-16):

# Guide d'utilisation TouchDesigner
*ici se trouve les directives concernant la méthodologie de TouchDesigner afin de maximiser le brain-power de tous*

## Nomenclatures
### Patches (*.toe*)
suivre cette nomenclature : 
```

    équipe_NomPatch_versionXY_STATUT_TonNom.toe

```
  où :
  ```

  - *équipe* = Noeud / Rhiz / Supra / Infra / LX / Back / etc

  - *NomPatch* = Nom facile à comprendre qui décrit essentiellement la raison d'être de la patch

  - *versionXY* = numéro de la version, remplacer *X*  en fonction du sprint et *Y* pour la version
            Exemple
                version1a --> version A de la patch au Sprint #1

  - *STATUT* = Statut de la patch [PROD, BUG, REV, GO]
            Où :
              - *PROD* = Production (on going changes)
              - *BUG* = Bug à corriger / non-fonctionnelle
              - *REV* = Peer-review en cours / Prêt à réviser
              - *GO* = Fichier approuvé techniquement et prêt à être déployé

  - TonNom = Ton nom

```
**NE JAMAIS UTILISER DE CHARACTÈRE SPÉCIAUX DANS VOTRE NOMENCLATURE**

### TOX
suivre cette nomenclature :
```

    équipe_FonctionTOX_versionXY_TAG.tox

```
  où :
  ```

  - *équipe* = Noeud / Rhiz / Supra / Infra / LX / Back / etc

  - *FonctionTOX* = Décrit la fonction principale du TOX, simple et concis.

  - *versionXY* = numéro de la version, remplacer *X*  en fonction du sprint et *Y* pour la version
            Exemple
                version1a --> version A de la patch au Sprint #1

  - *TAG* = Catégorie du tox [EFFET, DMX, OSC, TRIGGER, BASE, etc]
            Où :
              - *EFFET* = Visuel
              - *DMX* = Communication DMX
              - *OSC* = Communication OSC
              - *TRIGGER* = Qui trigger un événement
              - *BASE* = TOX de base

```
**NE JAMAIS UTILISER DE CHARACTÈRE SPÉCIAUX DANS VOTRE NOMENCLATURE**
<br>

## Bonnes Pratiques
SVP suivre autant que possible ces consignes, le 2min de plus va nous sauver des heures plus tard.
```

Toujours utiliser un TextDAT à chaque niveau (../) de votre patch qui contient :
  - Explication en détails des éléments
  - Explication de la logique employée
  - Explication des liens entre les données
  - Explication de cette patch dans l'écosystème.
  - Personne Ressource

Toujours utiliser des Null avant d'exporter des données, même si c'est vers un opérateur au même niveau.

Toujours créer des paramètres custom lorsque c'est applicable. Utiliser plusieurs pages de réglages au besoin, en autant que ce soit clair. 
Normaliser la nomenclature des paramêtres.

Utiliser des annotations (SHIFT + A) avec une belle couleur unique bien titré afin de "zoner" les composantes de programmation

Prendre le temps de rendre la patch esthétiquement belle (c'est mieux pour tout le monde)

Utiliser des Select pour éviter les longs branchements laids au besoin

Renommer les opérateurs d'importance et leur attribuer une couleur.

Faire en sorte que n'importe qui peut comprendre la logique et l'emplacement des opérateurs.

```

# Pour tout type de question, parlez à la personne technique de votre équipe ou à Sasha

<br>
<br>

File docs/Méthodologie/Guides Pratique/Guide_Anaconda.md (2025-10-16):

# 🧬 Guide d’utilisation — Anaconda (Projet Mycorhize)

## 🔧 Objectif
Ce guide explique comment :
1. Ouvrir et utiliser **Anaconda**.  
2. Déployer l’environnement existant à partir d’un **backup**.  
3. Installer de nouveaux packages via `pip install`.  
4. Lancer le projet sans modifier la configuration globale.

---

## 🪴 1. Lancer Anaconda

### Sous **Windows**
- Ouvre le **menu Démarrer**.
- Recherche **Anaconda Prompt** et ouvre-le.
- (Optionnel) Tu peux aussi utiliser **Anaconda Navigator** pour une interface graphique.

### Sous **macOS / Linux**
- Ouvre ton **Terminal**.
- Tape :
  ```
  anaconda-navigator
  ```
ou directement :
  ```
  conda activate mycorhize
  ```
🧩 2. Déployer le backup de l’environnement
Un fichier environment_backup.yml (ou environment_backup.txt) est fourni dans le dossier du projet.
C’est une sauvegarde complète de l’environnement Anaconda.

📦 Étapes :
Place le fichier de backup dans ton dossier du projet.

Ouvre Anaconda Prompt ou ton Terminal.

Exécute :
```
conda env create -f environment_backup.yml
```
ou si c’est un fichier .txt :
```
conda create --name mycorhize --file environment_backup.txt
```
Active l’environnement :
```
conda activate mycorhize
```
Vérifie que tout fonctionne :
```
python --version
pip list
```
🧠 3. Ajouter de nouveaux packages
L’environnement contient déjà les dépendances principales.
Si tu veux en ajouter d’autres, utilise pip :
```
pip install numpy
pip install opencv-python
pip install pyserial
```
💡 Astuce : utilise toujours pip (et non conda install) pour rester compatible avec le backup.

Pour vérifier :
```
pip show nom_du_package
```
🧼 4. Mettre à jour les dépendances
Si un nouveau requirements.txt ou environment_backup.yml est publié :
```
pip install -r requirements.txt
```
ou
```
conda env update -f environment_backup.yml --prune
```
🧭 5. Lancer le projet
Depuis l’environnement activé :
```
cd chemin/vers/le/projet
python main.py
```
Exemple :
```
cd "C:\Users\sasha\OneDrive - UQAM\Automne 2025\Projet Final\Mycorhize"
python app.py
```
💾 6. Sauvegarder l’environnement (optionnel)
Si tu fais des modifications importantes :
```
conda env export > environment_backup.yml
```
Cela permet de partager la configuration mise à jour avec toute l’équipe.

⚠️ Erreurs fréquentes
Problème	Solution
CommandNotFoundError: conda	Anaconda n’est pas ajouté au PATH. Ouvre via Anaconda Prompt.
PackagesNotFoundError	Le package n’existe pas dans conda. Utilise pip install.
Environment already exists	Supprime l’ancien avec conda env remove -n mycorhize, puis recrée-le.

🪶 Résumé rapide
Action	Commande
Activer l’environnement	conda activate mycorhize
Installer un package	pip install nom_du_package
Lister les packages	pip list
Mettre à jour depuis backup	conda env update -f environment_backup.yml
Lancer le projet	python main.py

📁 Structure typique du projet
css
Copy code
Mycorhize/
│
├── environment_backup.yml
├── requirements.txt
├── app.py
├── data/
├── src/
└── README.md
✳️ Conseil :
Si tu partages le projet avec d’autres personnes, vérifie que le fichier environment_backup.yml est bien à jour après toute modification des dépendances.

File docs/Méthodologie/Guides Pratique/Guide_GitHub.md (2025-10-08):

# 🌿 Guide GitHub Desktop

### Pour collaborer sur un dépôt existant

(sans créer de branches ni de dépôts)
<br>

## 🛏️ Introduction

GitHub Desktop est une application qui permet de collaborer sur un projet GitHub sans utiliser la ligne de commande. Elle simplifie les actions principales :

#### Pull → récupérer les dernières modifications

#### Commit → sauvegarder vos changements localement

#### Push → envoyer vos changements sur GitHub

#### Merge / Resolve conflicts → fusionner ou corriger les versions différentes
<br>

## 🩴 1. Cloner le dépôt (une seule fois)

#### a) Ouvrir GitHub Desktop

Lancez l’application et connectez-vous à votre compte GitHub.

#### b) Cliquer sur

File → Clone Repository…

#### c) Sélectionner le dépôt du projet

Il apparaîtra dans l’onglet GitHub.com.Cliquez sur Clone.

*💡 Cela crée une copie locale du projet sur votre ordinateur.*

<br>

## 🔄 2. Pull — Mettre à jour votre copie avant de travailler

Avant de modifier un fichier, faites toujours un Pull pour être à jour.

Dans la barre supérieure :➡️ Cliquez sur “Fetch origin”, puis sur “Pull origin” si disponible.

#### 🔸 Fetch = vérifier s’il y a des nouveautés sur GitHub🔸 Pull = télécharger ces nouveautés dans votre copie locale

#### ⚠️ Faites-le chaque fois avant de commencer à travailler.
<br>

## ✏️ 3. Commit — Enregistrer vos changements localement

### Quand vous modifiez ou ajoutez des fichiers dans le dossier du projet :

Revenez dans GitHub DesktopVous verrez la liste des fichiers modifiés dans la colonne de gauche.

Cochez les fichiers que vous voulez enregistrer.

En bas à gauche, écrivez :

*Summary : phrase courte et claire*

(Optionnel) Description plus longue en dessous
<br>

Exemples :

*Ajout du schéma du rhizome*

*Correction du bug d’affichage de la canopée*

*Mise à jour du moodboard*

*Cliquez sur Commit to main.*

#### 💾 Vous venez de créer un commit local, une sauvegarde de vos changements sur votre machine.

<br>

## ☁️ 4. Push — Envoyer vos changements sur GitHub

Une fois votre commit créé, un bouton “Push origin” apparaît en haut.➡️ Cliquez dessus.

**Cela envoie vos modifications sur GitHub pour que toute l’équipe les voie.**

*🧠 Astuce : attendez quelques secondes après un push pour que le dépôt en ligne se mette à jour.*

<br>

## 🔁 5. Merge automatique (Pull avec changements)

Si quelqu’un d’autre a modifié les mêmes fichiers pendant que vous travailliez :

Quand vous cliquerez sur Pull origin, GitHub Desktop essaiera de fusionner (merge) automatiquement.

Si tout se passe bien, un message s’affiche :✅ This branch is up to date with origin/main.

<br>

## ⚠️ 6. Conflits (quand deux versions se contredisent)

Il peut arriver qu’un fichier ait été modifié en même temps par deux personnes.

<br>

**Symptômes :**

*Le pull échoue.*

**Message rouge :“We found some conflicts that need to be resolved.”**

#### Étapes à suivre :

GitHub Desktop vous indique le ou les fichiers en conflit.Cliquez sur “Open in Visual Studio Code” (ou l’éditeur par défaut).

Dans le fichier, vous verrez ceci :
<br>

```
<<<<<<< HEAD
Votre version locale
=======
Version sur GitHub
>>>>>>> main
```
<br>

**Choisissez ce que vous voulez garder, supprimez les lignes inutiles et les marqueurs (<<<<<<<, =======, >>>>>>>).**

**Enregistrez le fichier.**

<br>

**Retournez dans GitHub Desktop :**

**Cochez le fichier résolu.**

<br>

**Écrivez un message de commit commeRésolution du conflit dans fichier.txt.**

<br>

**Cliquez sur Commit merge.**

<br>

**Enfin, cliquez sur Push origin.**

<br>

## 📊 7. Vérifier l’historique

Vous pouvez voir toutes les modifications passées dans l’onglet History :

*Nom de la personne*
<br>
*Message du commit*
<br>
*Fichiers modifiés*
<br>
Très pratique pour comprendre l’évolution du projet.

<br>

## 🤌 Schéma récapitulatif

🚞️ Étapes de base :
<br>
```
    ┌──────────────┐
    │   git pull   │ ←── Télécharge les dernières modifs
    └──────┬───────┘
           │
    ┌──────▼───────┐
    │   git add .  │ ←── Sélectionne les fichiers modifiés
    └──────┬───────┘
           │
    ┌──────▼───────┐
    │ git commit -m│ ←── Enregistre localement les changements
    └──────┬───────┘
           │
    ┌──────▼───────┐
    │   git push   │ ←── Envoie les changements sur GitHub
    └──────────────┘

```
<br>
🔁 Répétez ce cycle chaque fois que vous travaillez sur le projet.
<br>
💡 Bonnes pratiques d’équipe
<br>
✅ Toujours Pull avant de commencer à travailler✅ Commit souvent avec des messages clairs✅ Push dès que possible pour éviter les conflits✅ Si vous voyez un conflit, respirez 😄, puis suivez les étapes ci-dessus✅ Ne supprimez pas de fichiers du projet sans en parler à l’équipe
<br>

## 🛠️ Résumé visuel (terminologie)

<br>

*Pull*

**Récupérer**

**Met à jour votre dossier avec les dernières versions du projet**

<br>

*Commit*

**Sauvegarder localement**

**Enregistre vos modifications sur votre ordinateur**

<br>

*Push*

**Envoyer**

**Met à jour GitHub avec vos commits**

<br>

*Merge*

**Fusionner**

**Combine deux versions différentes d’un fichier**

<br>

*Conflict*

**Désaccord**

**Git vous demande de choisir entre deux versions**

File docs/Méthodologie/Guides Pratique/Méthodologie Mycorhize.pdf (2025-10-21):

# {Mycorhize}

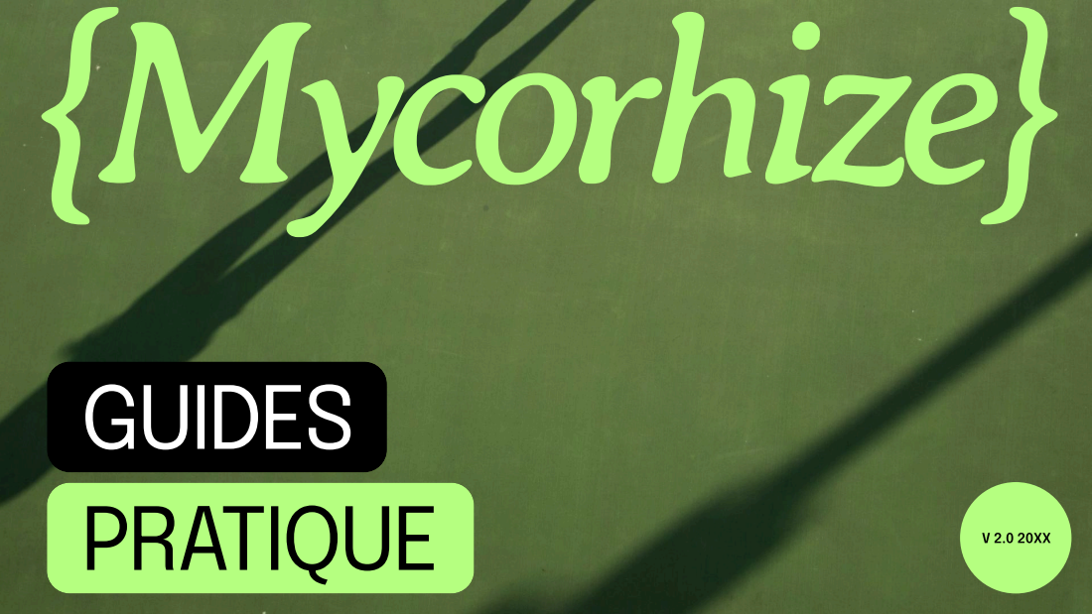
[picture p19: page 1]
Guides; pratique

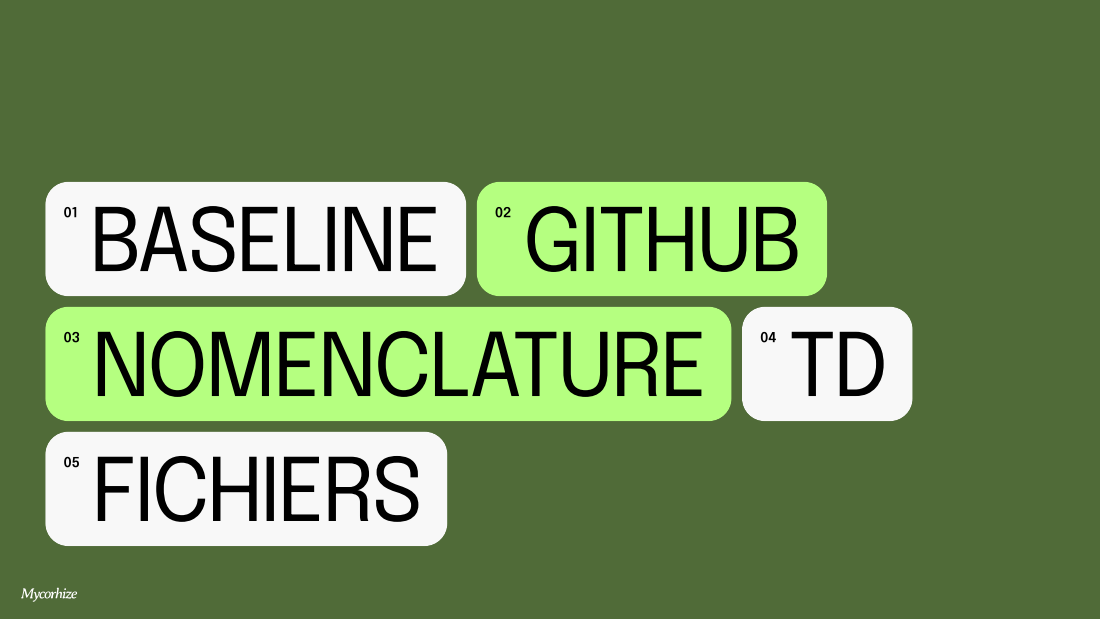
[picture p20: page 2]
Mycorhize; 01Baseline 02Github 03Nomenclature 04; 05 Fichiers

# 01 Guide

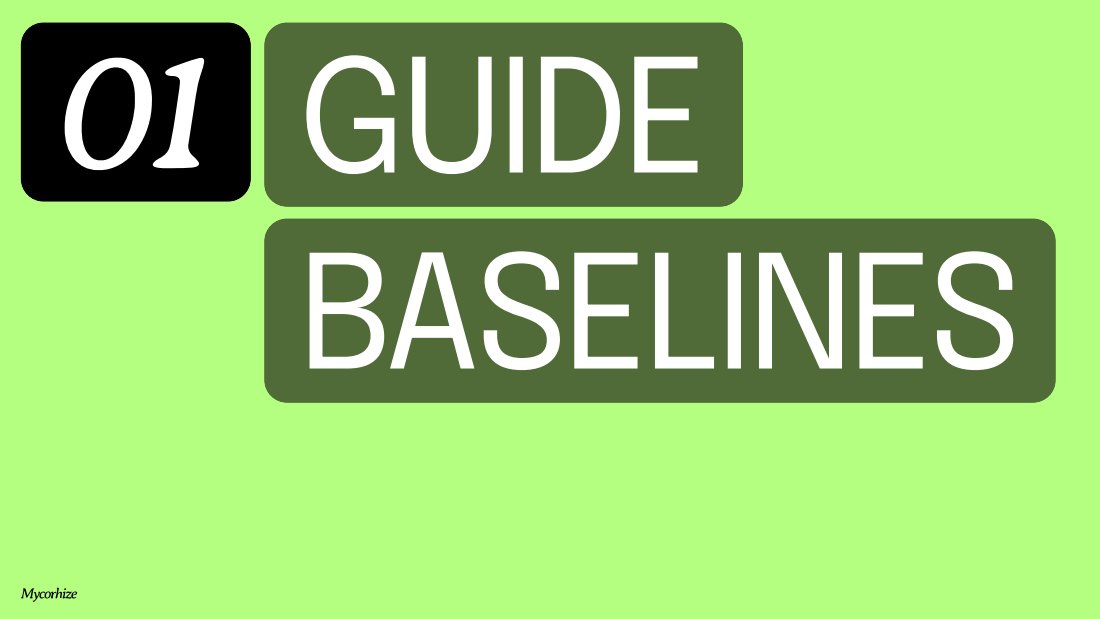
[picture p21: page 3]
Baselines

# Tout projet se doit d’avoir une structure fiable, efficace et adaptée

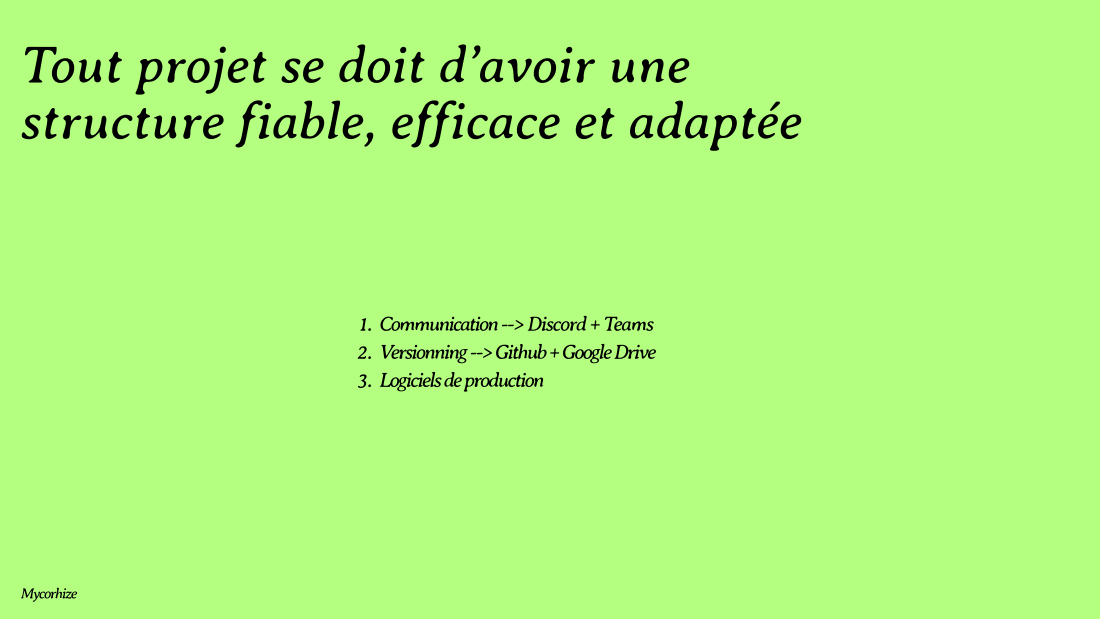
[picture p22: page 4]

Communication --> Discord + Teams
Versionning --> Github + Google Drive
Logiciels de production

# 02 Guide

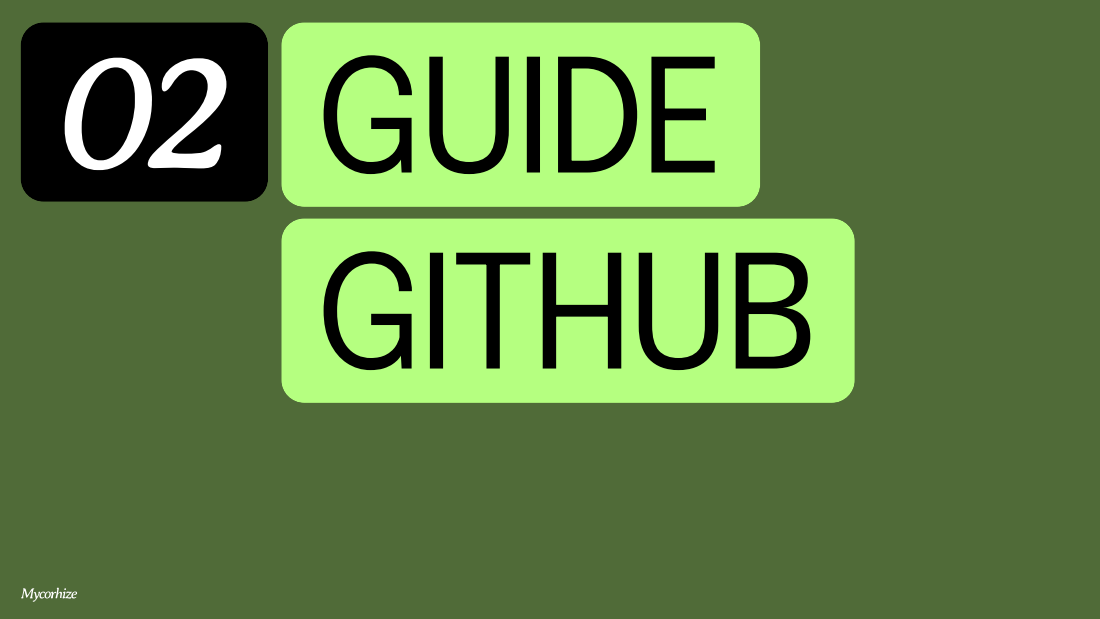
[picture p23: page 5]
Github

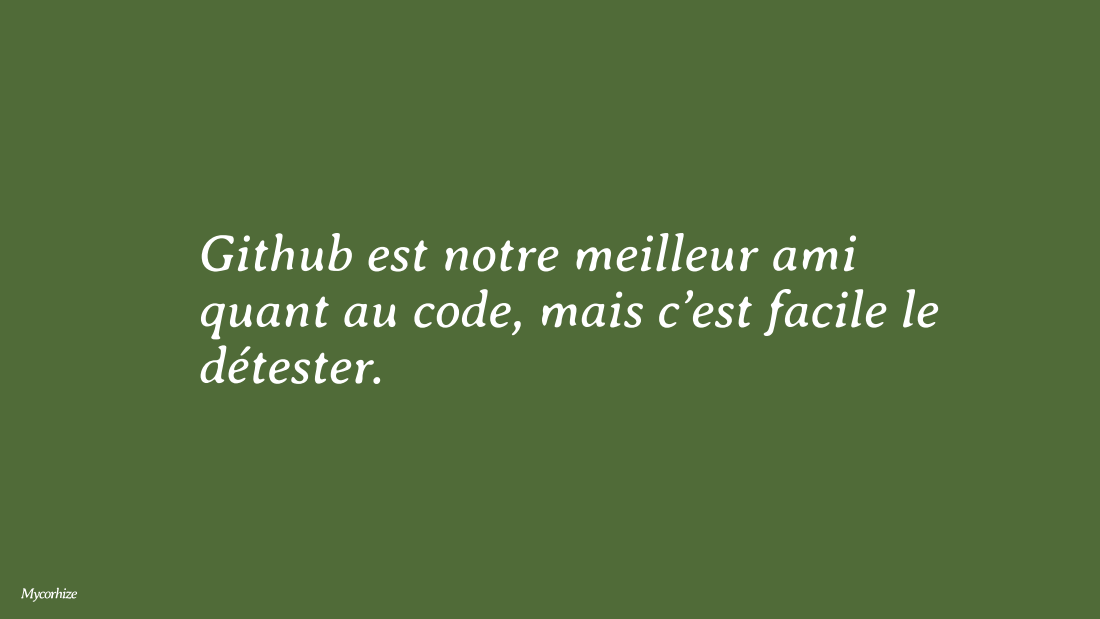
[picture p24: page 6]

Github est notre meilleur ami
quant au code, mais c’est facile le
détester.

# Terminologie

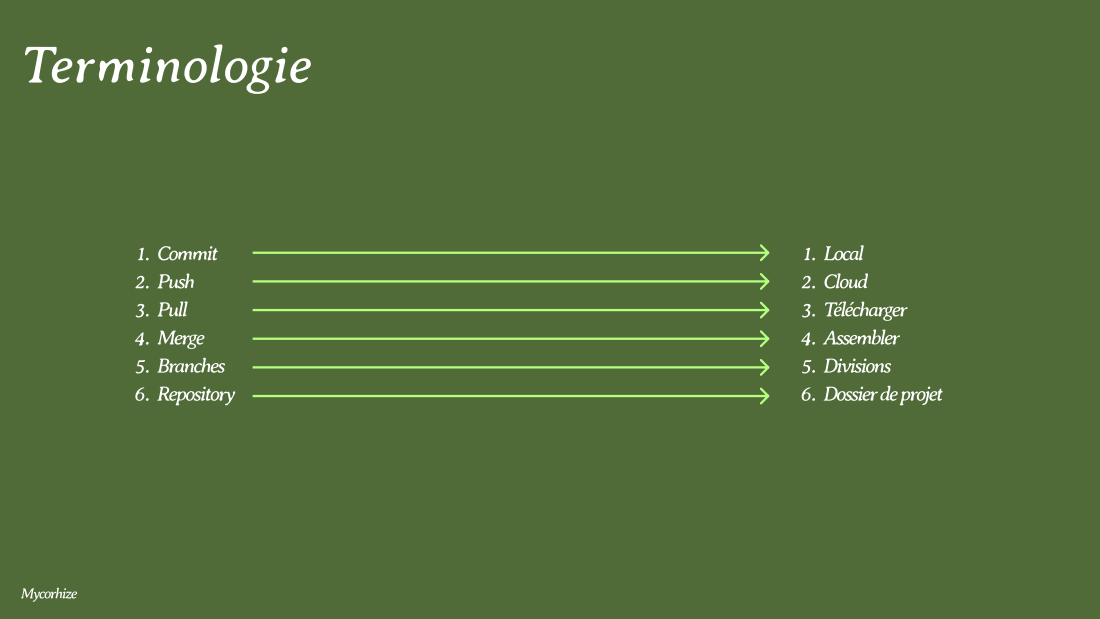
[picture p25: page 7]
Commit; Push Pull; Merge; Branches; Repository; Local Cloud; Télécharger; Assembler; Divisions; Dossier de projet

# Aide-mémoire

Toujours nommer ses commits de façon normalisée, claire et concise Communication entre les membres de la branche pour ne pas avoir de conflits Push ce qui doit être pushed seulement Pull régulièrement Courte description du commit, si nécessaire (mais recommandé) Demander de l’aide pour résoudre les conflits (don’t be a hero si t’es pas sûr.e)

# À faire

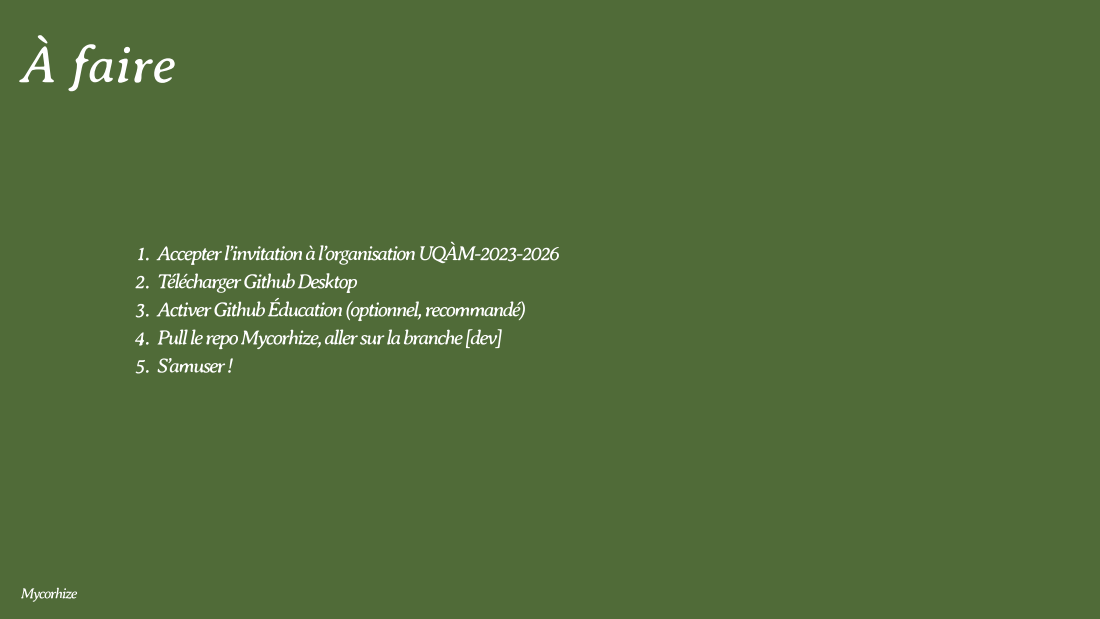
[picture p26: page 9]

Accepter l’invitation à l’organisation UQÀM-2023-2026
Télécharger Github Desktop
Activer Github Éducation (optionnel, recommandé)
Pull le repo Mycorhize, aller sur la branche [dev]
S’amuser !

# 03 Guide

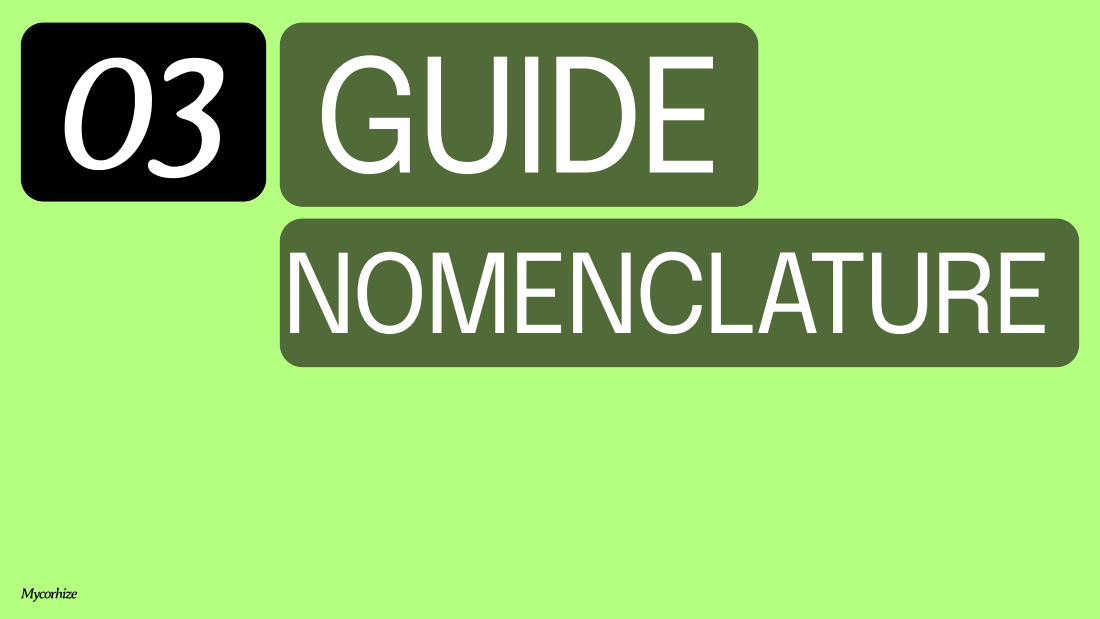
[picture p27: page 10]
nomenclature

# SVP

# C’EST ULTRA IMPORTANT DE

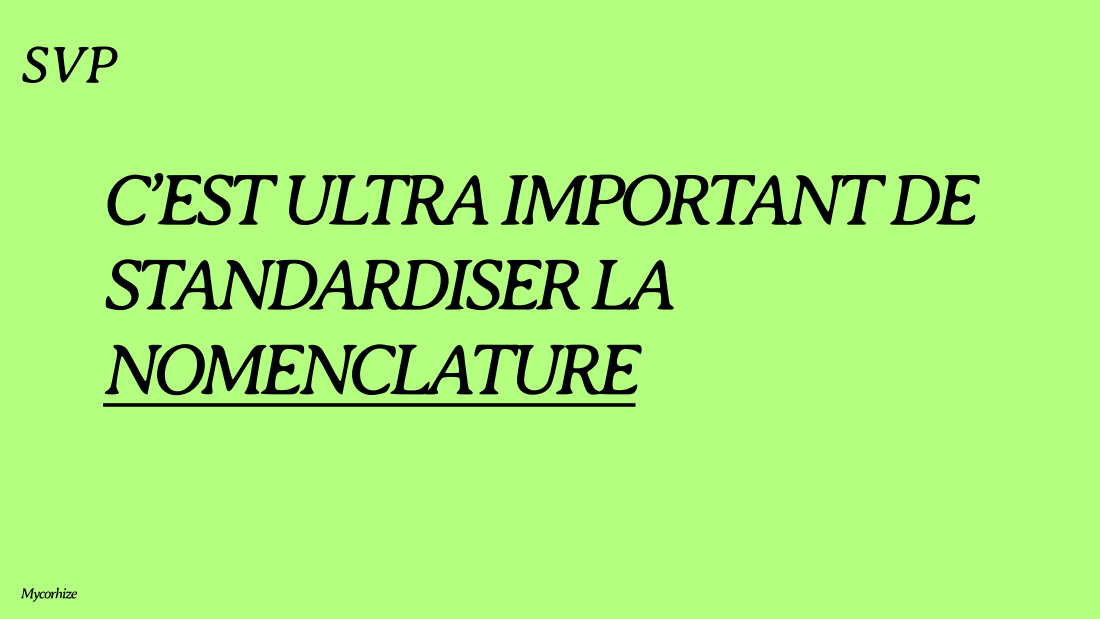
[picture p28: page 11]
STANDARDISER LA NOMENCLATURE

# Style de nomenclature

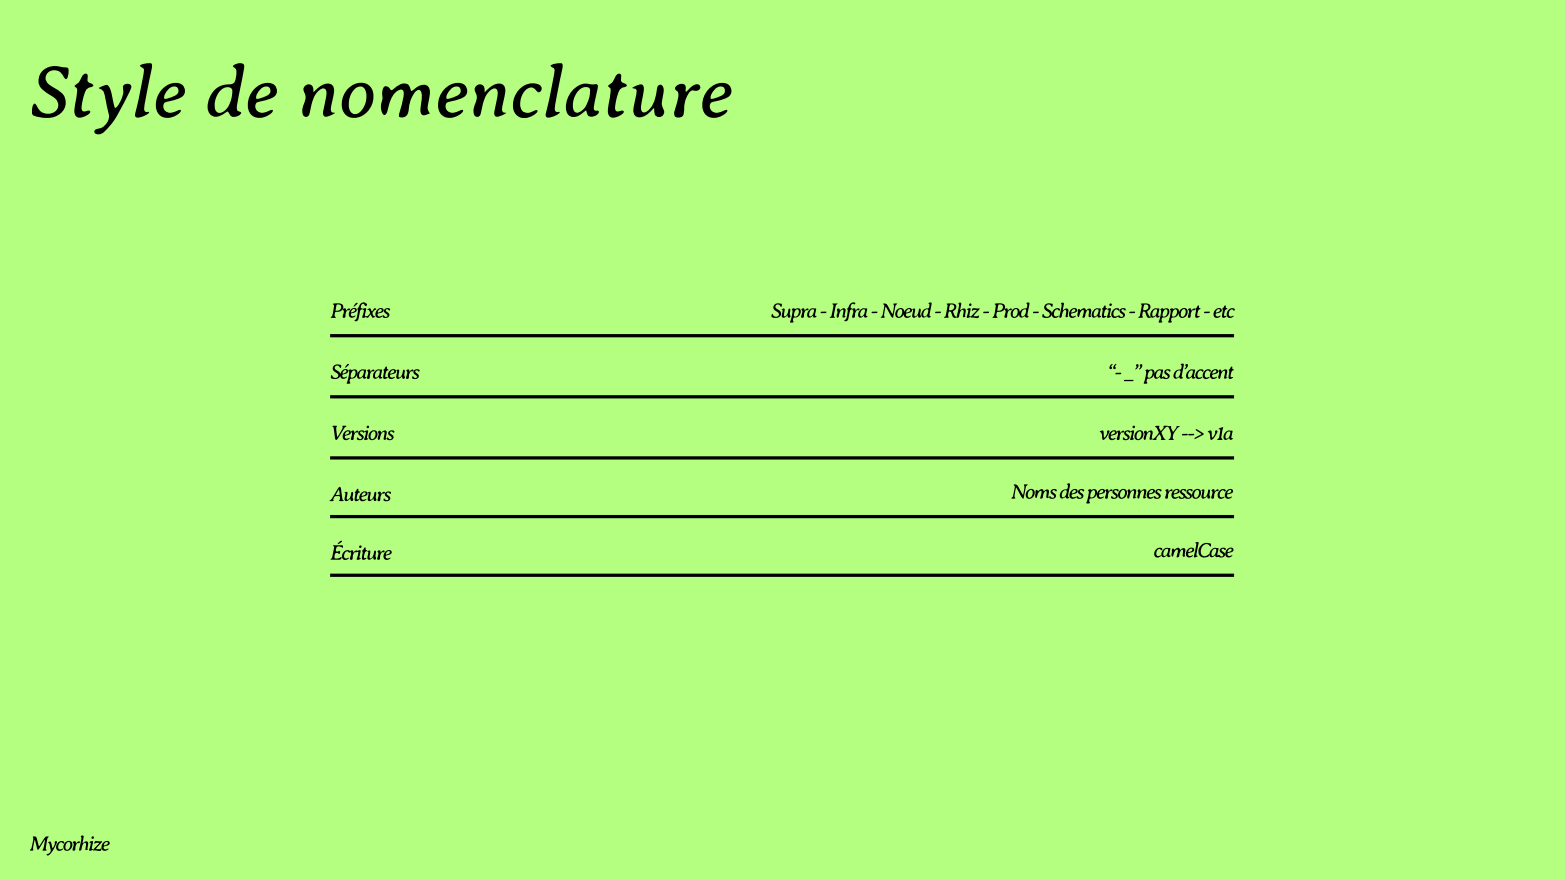
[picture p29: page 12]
Préfixes; Supra - Infra - Noeud - Rhiz - Prod - Schematics - Rapport - etc; Séparateurs; “- _” pas d’accent; Versions; Auteurs; Écriture; versionXY --> v1a; camelCase

Noms des personnes ressource

# 04 Guide

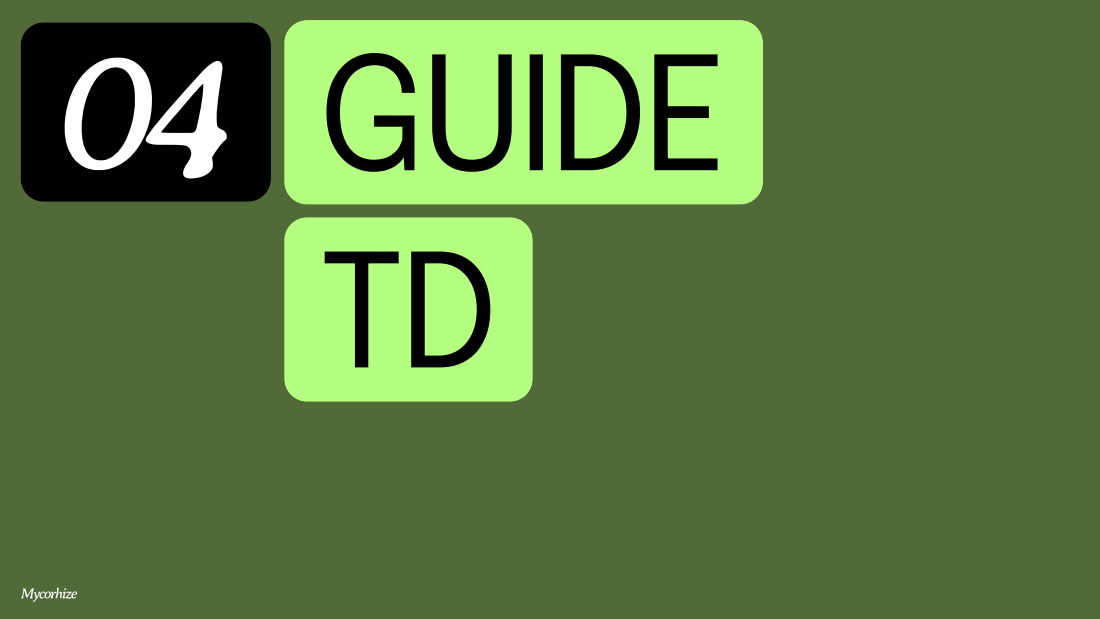
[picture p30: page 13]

## équipe_NomPatch_versionXY_STATUT_TonNom.toe

## équipe_FonctionTOX_versionXY_TAG.tox

*équipe* = Noeud / Rhiz / Supra / Infra / LX / Back / etc

*NomPatch* = Nom facile à comprendre qui décrit essentiellement la raison d'être de la patch

*versionXY* = numéro de la version, remplacer *X* en fonction du sprint et *Y* pour la version Exemple
version1a --> version A de la patch au Sprint #1

*STATUT* = Statut de la patch [PROD, BUG, REV, GO] Où :
- *PROD* = Production (on going changes)
- *BUG* = Bug à corriger / non-fonctionnelle
- *REV* = Peer-review en cours / Prêt à réviser
- *GO* = Fichier approuvé techniquement et prêt à être déployé

TonNom = Ton nom

*équipe* = Noeud / Rhiz / Supra / Infra / LX / Back / etc

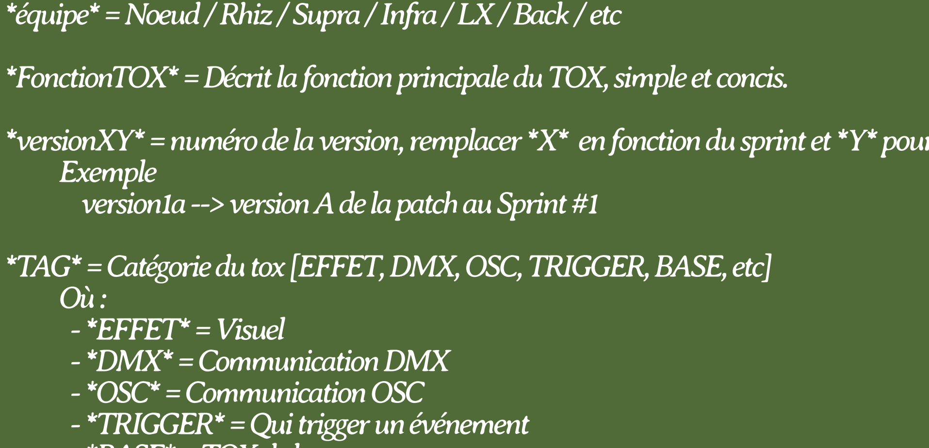
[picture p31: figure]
Exemple; Où : - *EFFET* = Visuel - *DMX* = Communication DMX - *OSC* = Communication OSC - *TRIGGER* = Qui trigger un événement

*FonctionTOX* = Décrit la fonction principale du TOX, simple et concis.

*versionXY* = numéro de la version, remplacer *X* en fonction du sprint et *Y* pour la version

version1a --> version A de la patch au Sprint #1

*TAG* = Catégorie du tox [EFFET, DMX, OSC, TRIGGER, BASE, etc]

- *BASE* = TOX de base

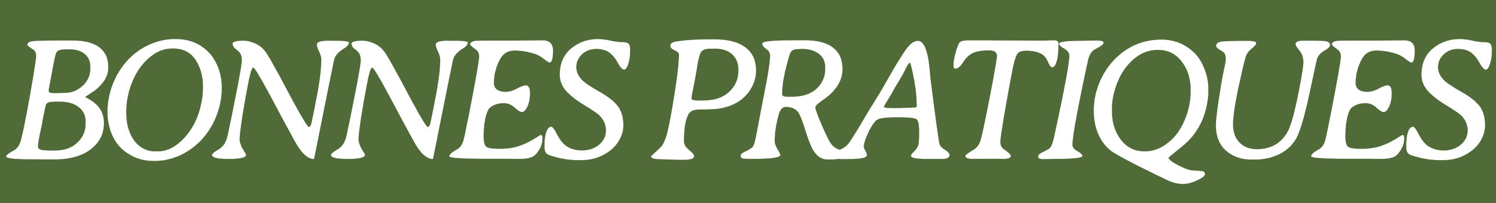
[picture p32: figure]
Bonnes Pratiques

### Toujours utiliser un TextDAT à chaque niveau (../) de votre patch qui contient : - Explication en détails des éléments - Explication de la logique employée - Explication des liens entre les données

- Explication de cette patch dans l'écosystème.

### - Personne Ressource

Toujours utiliser des Null avant d'exporter des données, même si c'est vers un opérateur au même niveau.

Toujours créer des paramètres custom lorsque c'est applicable. Utiliser plusieurs pages de réglages au besoin, en autant que ce soit clair. Normaliser la nomenclature des paramêtres.

Utiliser des annotations (SHIFT + A) avec une belle couleur unique bien titré afin de "zoner" les composantes de programmation

### Prendre le temps de rendre la patch esthétiquement belle (c'est mieux pour tout le monde)

### Utiliser des Select pour éviter les longs branchements laids au besoin

Renommer les opérateurs d'importance et leur attribuer une couleur.

Faire en sorte que n'importe qui peut comprendre la logique et l'emplacement des opérateurs.

# 05 Fichiers

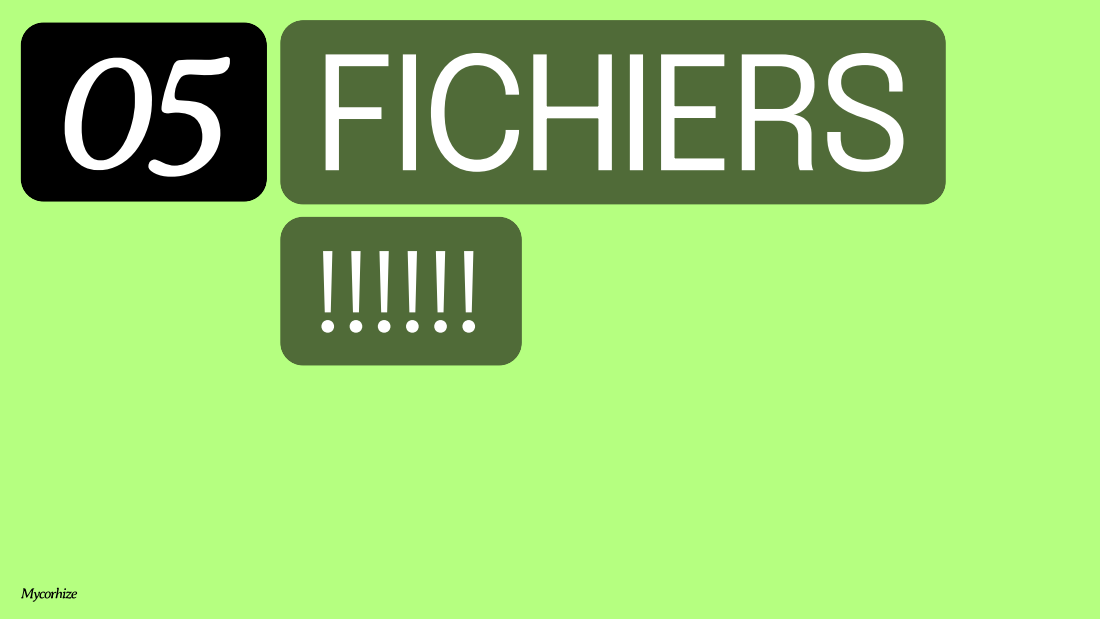
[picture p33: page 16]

# Où placer mes fichiers ?

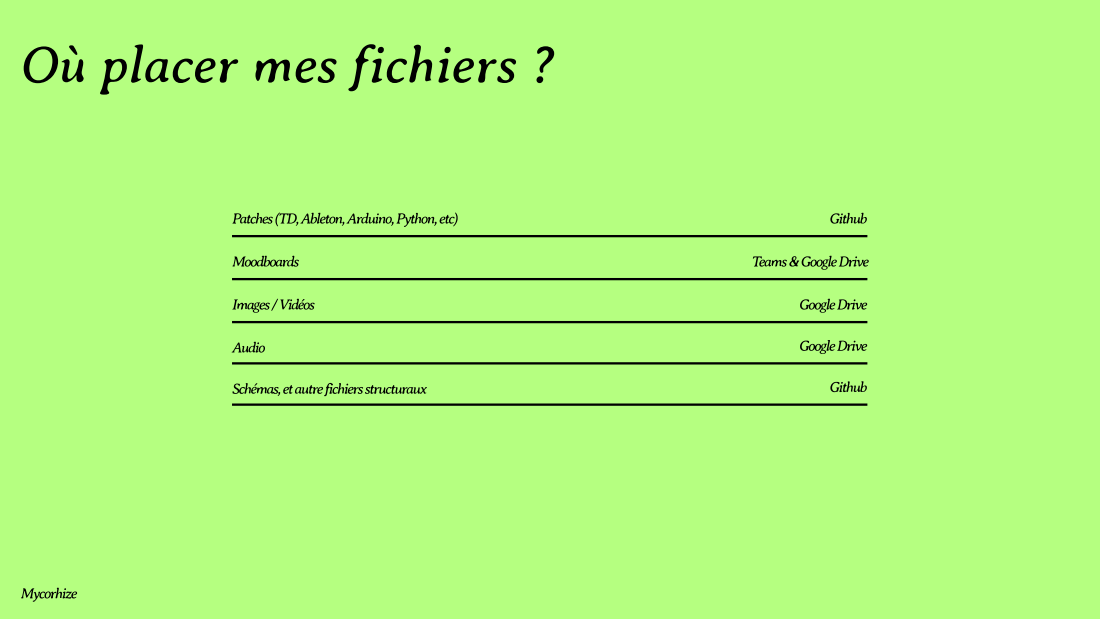
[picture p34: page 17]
Patches (TD, Ableton, Arduino, Python, etc); Github; Moodboards; Teams & Google Drive; Images / Vidéos; Audio; Google Drive

Schémas, et autre fichiers structuraux

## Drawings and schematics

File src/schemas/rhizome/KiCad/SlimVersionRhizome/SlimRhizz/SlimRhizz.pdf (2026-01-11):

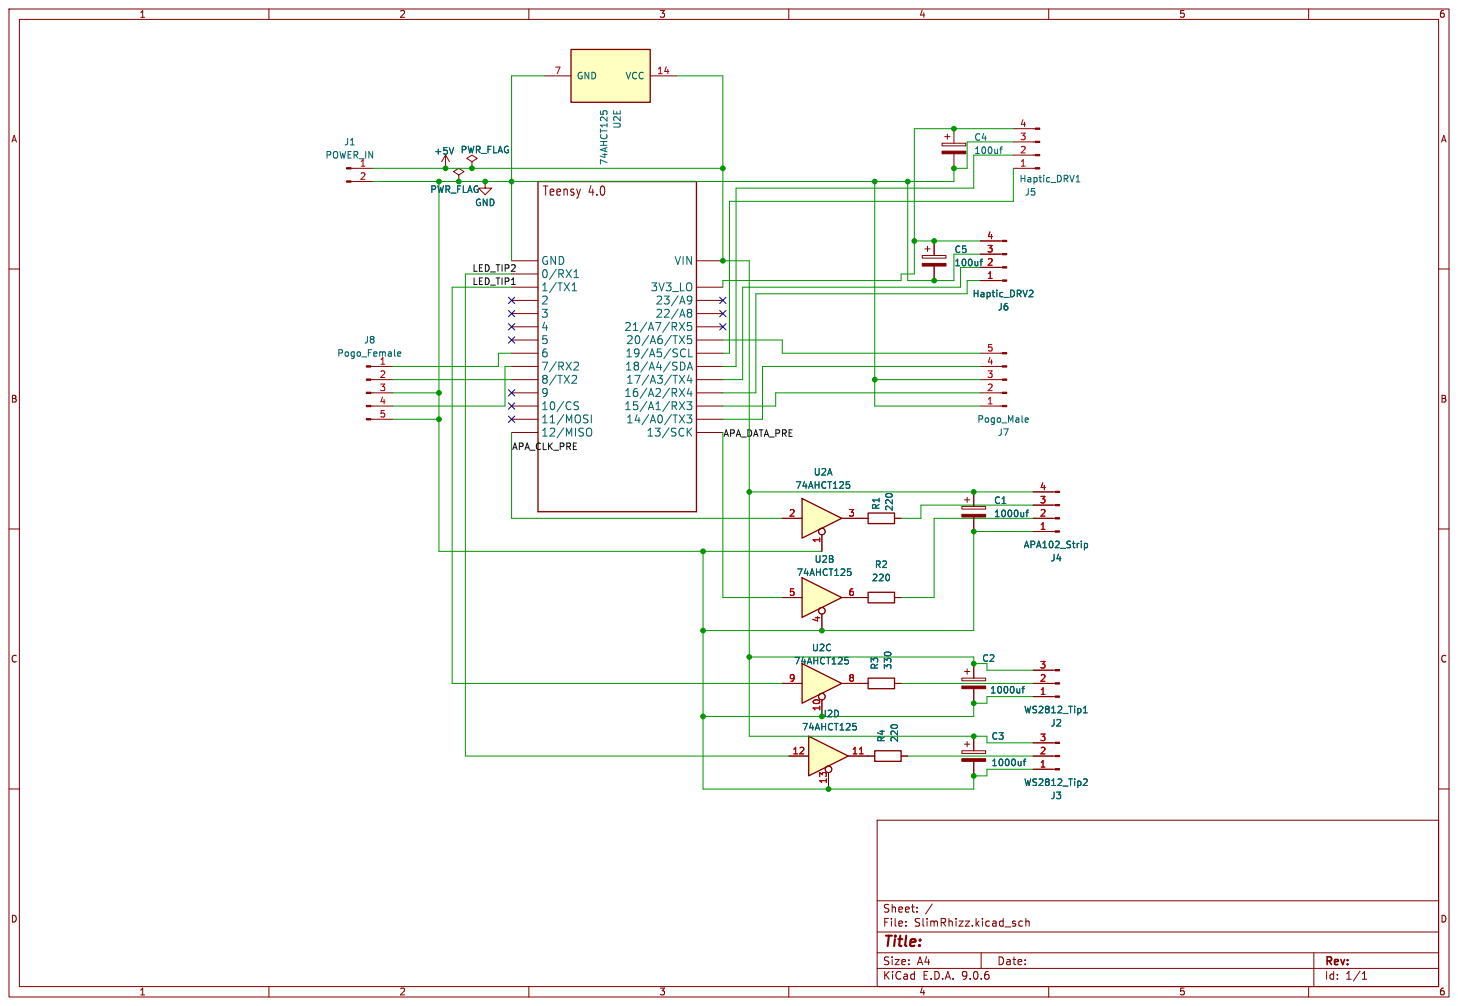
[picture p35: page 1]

Id: 1/1 Title: File: SlimRhizz.kicad_sch Sheet: / R3 330 R2

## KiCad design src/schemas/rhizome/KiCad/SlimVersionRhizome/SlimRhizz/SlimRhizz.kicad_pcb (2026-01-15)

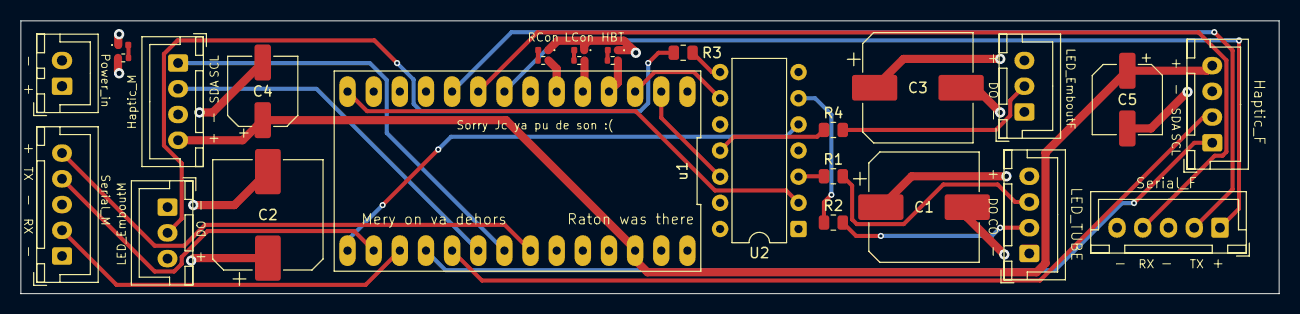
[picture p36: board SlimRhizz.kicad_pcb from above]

Board: 4 copper layers, 122.2 x 26.5 mm, 27 parts (0 on the bottom side), 32 nets.

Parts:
C1, C2, C3: 1000uf; CP_Elec_10x10.5
C4, C5: 100uf; CP_Elec_6.3x5.4
D1: PWR; LED_0402_1005Metric
HBT: HBT; LED_0402_1005Metric
J1: POWER_IN; JST_XH_B2B-XH-A_1x02_P2.50mm_Vertical
J2: WS2812_Tip1; JST_XH_B3B-XH-A_1x03_P2.50mm_Vertical
J3: WS2812_Tip2; JST_XH_B3B-XH-A_1x03_P2.50mm_Vertical
J4: APA102_Strip; JST_XH_B4B-XH-A_1x04_P2.50mm_Vertical
J5: Haptic_DRV1; JST_XH_B4B-XH-A_1x04_P2.50mm_Vertical
J6: Haptic_DRV2; JST_XH_B4B-XH-A_1x04_P2.50mm_Vertical
J7: Pogo_Male; JST_XH_B5B-XH-A_1x05_P2.50mm_Vertical
J8: Pogo_Female; JST_XH_B5B-XH-A_1x05_P2.50mm_Vertical
LCon: L-Connect; LED_0402_1005Metric
PWR: 1000; R_0402_1005Metric
R1, R2, R3, R4: 220; R_0805_2012Metric
R6, R7, R8: 330; R_0402_1005Metric
RCon: R-Connect; LED_0402_1005Metric
U2: 74AHCT125; DIP-14_W7.62mm
u1: Teensy4.0r0

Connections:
+5V: C1.1, C2.1, C3.1, J1.1, J2.3, J3.3, J4.4, PWR.2, U2.14 (VCC), u1.VIN
/APA_CLK_PRE: U2.2, u1.12 (12/MISO)
/APA_DATA_PRE: U2.5, u1.13 (13/SCK)
/LED_TIP1: U2.9, u1.1 (1/TX1)
/LED_TIP2: U2.12, u1.0 (0/RX1)
GND: C1.2, C2.2, C3.2, C4.2, C5.2, D1.1 (K), HBT.1 (K), J1.2, J2.1, J3.1, J4.1, J5.3, J6.3, J7.1, J7.3, J8.3, J8.5, LCon.1 (K), RCon.1 (K), U2.1, U2.4, U2.7 (GND), U2.10, U2.13, u1.GND
unnamed: D1.2 (A), PWR.1
unnamed: HBT.2 (A), R6.2
unnamed: LCon.2 (A), R7.2
unnamed: R8.2, RCon.2 (A)
unnamed: J2.2, R3.2
unnamed: J3.2, R4.2
unnamed: J4.2, R2.2
unnamed: J4.3, R1.2
unnamed: J5.1, u1.19 (19/A5/SCL)
unnamed: J5.2, u1.18 (18/A4/SDA)
unnamed: C4.1, C5.1, J5.4, J6.4, u1.3.3V (3V3_LO)
unnamed: J6.1, u1.16 (16/A2/RX4)
unnamed: J6.2, u1.17 (17/A3/TX4)
unnamed: J7.2, u1.15 (15/A1/RX3)
unnamed: J7.4, u1.14 (14/A0/TX3)
unnamed: J7.5, u1.20 (20/A6/TX5)
unnamed: J8.1, u1.6
unnamed: J8.2, u1.8 (8/TX2)
unnamed: J8.4, u1.7 (7/RX2)
unnamed: R1.1, U2.3
unnamed: R2.1, U2.6
unnamed: R3.1, U2.8
unnamed: R4.1, U2.11
unnamed: R6.1, u1.2
unnamed: R7.1, u1.3
unnamed: R8.1, u1.4

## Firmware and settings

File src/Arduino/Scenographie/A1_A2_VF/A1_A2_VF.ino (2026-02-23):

// Contrôle Actionneur - Version Fusionnée (OSC + Fin de course)
#include <SPI.h>
#include <Ethernet.h>
#include <EthernetUdp.h>
#include <OSCMessage.h>

// --- PINS ---
const int buttonPin1 = 9;
const int buttonPin2 = A5;

const int RPWMA1 = 5;   // Retract
const int LPWMA1 = 6;   // Extend
const int R_ENA1 = 7;
const int L_ENA1 = 8;

const int RPWMA2 = A1;  // Retract
const int LPWMA2 = A2;  // Extend
const int R_ENA2 = A3;
const int L_ENA2 = A4;

// --- ETHERNET / OSC ---
byte mac[] = { 0x02, 0x00, 0x00, 0x00, 0x00, 0x01 };
IPAddress ip(10, 0, 2, 228);
EthernetUDP Udp;
const unsigned int localPort = 1111;

// --- TIMING ---
int pause = 500;
unsigned long lastOSCReception = 0;
const unsigned long timeoutNuit = 10000;
const unsigned long retractFailsafe = 3000;   // max retract time before forced stop
const unsigned long directionChangePause = 100; // pause before each direction change

// --- MODES & STATES ---
bool modeNuit = false;

enum MouvementState { AVANT, PAUSE_BEFORE_RETRACT, PAUSE1, ARRIERE, PAUSE_BEFORE_EXTEND, PAUSE2 };
MouvementState mouvementState = AVANT;
unsigned long mouvementTimer = 0;
unsigned long retractStartTime = 0;

enum NuitState { NUIT_PAUSE_BEFORE_RETRACT, NUIT_SORT, NUIT_PAUSE_BEFORE_EXTEND, NUIT_ENTER };
NuitState nuitState = NUIT_SORT;
unsigned long nuitTimer = 0;
unsigned long nuitRetractStartTime = 0;

void stopAll() {
  digitalWrite(LPWMA1, LOW); digitalWrite(RPWMA1, LOW);
  digitalWrite(LPWMA2, LOW); digitalWrite(RPWMA2, LOW);
}

void setup() {
  Serial.begin(9600);

  pinMode(RPWMA1, OUTPUT); pinMode(LPWMA1, OUTPUT);
  pinMode(R_ENA1, OUTPUT); pinMode(L_ENA1, OUTPUT);
  pinMode(RPWMA2, OUTPUT); pinMode(LPWMA2, OUTPUT);
  pinMode(R_ENA2, OUTPUT); pinMode(L_ENA2, OUTPUT);
  pinMode(buttonPin1, INPUT);
  pinMode(buttonPin2, INPUT);

  digitalWrite(R_ENA1, HIGH); digitalWrite(L_ENA1, HIGH);
  digitalWrite(R_ENA2, HIGH); digitalWrite(L_ENA2, HIGH);

  // Drive to retracted position on boot, wait for both limit switches
  Serial.println("Homing: retracting...");
  digitalWrite(LPWMA1, LOW); digitalWrite(RPWMA1, HIGH);
  digitalWrite(LPWMA2, LOW); digitalWrite(RPWMA2, HIGH);

  unsigned long homingStart = millis();

  // Wait until both buttons are hit before starting the cycle
  while (digitalRead(buttonPin1) == 1 || digitalRead(buttonPin2) == 1) {
    if (digitalRead(buttonPin1) == 0) {
      digitalWrite(LPWMA1, LOW);
    }
    if (digitalRead(buttonPin2) == HIGH) {
      digitalWrite(LPWMA2, LOW);
    }
    // Failsafe during homing: stop after 2s if switches not detected
    if (millis() - homingStart >= retractFailsafe) {
      Serial.println("Homing failsafe triggered — stopping.");
      stopAll();
      break;
    }
  }

  stopAll();
  Serial.println("Homing done. Starting cycle.");

  Ethernet.begin(mac, ip);
  Udp.begin(localPort);

  mouvementTimer = millis();
  nuitTimer = millis();
}

void loop() {
  checkOSCMessages();

  if (modeNuit) {
    mouvementNuit();
  } else {
    mouvement();
  }
}

// -------------------------------------------------------
// OSC
// -------------------------------------------------------
void checkOSCMessages() {
  OSCMessage msg;
  int size = Udp.parsePacket();

  if (size > 0) {
    lastOSCReception = millis();
    modeNuit = false;

    while (size--) {
      msg.fill(Udp.read());
    }

    if      (msg.getInt(0) == 0) pause = 50;
    else if (msg.getInt(0) == 1) pause = 1000;
    else if (msg.getInt(0) == 2) pause = 2500;

    msg.empty();
  }

  if (millis() - lastOSCReception > timeoutNuit) {
    modeNuit = true;
  }
}

// -------------------------------------------------------
// MOUVEMENT NORMAL
// AVANT               → extend for 1500ms
// PAUSE_BEFORE_RETRACT→ 500ms stop before reversing
// PAUSE1              → configurable pause
// ARRIERE             → retract until BOTH limit switches hit (2s failsafe)
// PAUSE_BEFORE_EXTEND → 500ms stop before reversing
// PAUSE2              → configurable pause
// -------------------------------------------------------
void mouvement() {
  unsigned long maintenant = millis();

  int b1 = digitalRead(buttonPin1);
  int b2 = digitalRead(buttonPin2);

  switch (mouvementState) {

    case AVANT:
      digitalWrite(RPWMA1, LOW); digitalWrite(LPWMA1, HIGH);
      digitalWrite(RPWMA2, LOW); digitalWrite(LPWMA2, HIGH);

      if (maintenant - mouvementTimer >= 1500) {
        stopAll();
        mouvementTimer = maintenant;
        mouvementState = PAUSE_BEFORE_RETRACT;
        Serial.println("--- PAUSE before retract (500ms) ---");
      }
      break;

    case PAUSE_BEFORE_RETRACT:
      if (maintenant - mouvementTimer >= directionChangePause) {
        mouvementTimer = maintenant;
        mouvementState = PAUSE1;
        Serial.println("--- PAUSE 1 ---");
      }
      break;

    case PAUSE1:
      if (maintenant - mouvementTimer >= pause) {
        retractStartTime = maintenant;
        mouvementTimer = maintenant;
        mouvementState = ARRIERE;
        Serial.println("Mouvement: RETRACT (until limit switches or 2s failsafe)");
      }
      break;

    case ARRIERE: {
      bool failsafe = (maintenant - retractStartTime >= retractFailsafe);

      if (failsafe) {
        stopAll();
        Serial.println("RETRACT FAILSAFE triggered — forcing PAUSE 2");
        mouvementTimer = maintenant;
        mouvementState = PAUSE_BEFORE_EXTEND;
        break;
      }

      // Stop each motor independently as its switch is hit
      if (b1 == 1) { digitalWrite(LPWMA1, LOW); digitalWrite(RPWMA1, HIGH); }
      else          { digitalWrite(LPWMA1, LOW); digitalWrite(RPWMA1, LOW); }

      if (b2 == 1) { digitalWrite(RPWMA2, HIGH); digitalWrite(LPWMA2, LOW); }
      else          { digitalWrite(RPWMA2, LOW); digitalWrite(LPWMA2, LOW); }

      // Advance when BOTH are fully retracted
      if (b1 == 0 && b2 == 0) {
        stopAll();
        mouvementTimer = maintenant;
        mouvementState = PAUSE_BEFORE_EXTEND;
        Serial.println("--- PAUSE before extend (500ms) ---");
      }
      break;
    }

    case PAUSE_BEFORE_EXTEND:
      if (maintenant - mouvementTimer >= directionChangePause) {
        mouvementTimer = maintenant;
        mouvementState = PAUSE2;
        Serial.println("--- PAUSE 2 ---");
      }
      break;

    case PAUSE2:
      if (maintenant - mouvementTimer >= pause) {
        mouvementTimer = maintenant;
        mouvementState = AVANT;
        Serial.println("Mouvement: EXTEND >>>");
      }
      break;
  }
}

// -------------------------------------------------------
// MODE NUIT
// Same logic — retract until limit switches (with 2s failsafe),
// 500ms pause before each direction change, then extend for 1000ms
// -------------------------------------------------------
void mouvementNuit() {
  unsigned long maintenant = millis();

  int b1 = digitalRead(buttonPin1);
  int b2 = digitalRead(buttonPin2);

  switch (nuitState) {

    case NUIT_PAUSE_BEFORE_RETRACT:
      if (maintenant - nuitTimer >= directionChangePause) {
        nuitRetractStartTime = maintenant;
        nuitTimer = maintenant;
        nuitState = NUIT_SORT;
        Serial.println("Nuit: retracting...");
      }
      break;

    case NUIT_SORT: {
      bool failsafe = (maintenant - nuitRetractStartTime >= retractFailsafe);

      if (failsafe) {
        stopAll();
        Serial.println("Nuit RETRACT FAILSAFE triggered");
        nuitTimer = maintenant;
        nuitState = NUIT_PAUSE_BEFORE_EXTEND;
        break;
      }

      if (b1 == 0) { digitalWrite(RPWMA1, LOW); digitalWrite(LPWMA1, LOW); }
      else          { digitalWrite(LPWMA1, LOW); digitalWrite(RPWMA1, HIGH); }

      if (b2 == 0) { digitalWrite(RPWMA2, LOW); digitalWrite(LPWMA2, LOW); }
      else          { digitalWrite(LPWMA2, LOW); digitalWrite(RPWMA2, HIGH); }

      if (b1 == 0 && b2 == 0) {
        stopAll();
        nuitTimer = maintenant;
        nuitState = NUIT_PAUSE_BEFORE_EXTEND;
        Serial.println("Nuit: both retracted — pause before extending...");
      }
      break;
    }

    case NUIT_PAUSE_BEFORE_EXTEND:
      if (maintenant - nuitTimer >= directionChangePause) {
        nuitTimer = maintenant;
        nuitState = NUIT_ENTER;
        Serial.println("Nuit: extending...");
      }
      break;

    case NUIT_ENTER:
      digitalWrite(LPWMA1, HIGH); digitalWrite(RPWMA1, LOW);
      digitalWrite(LPWMA2, HIGH); digitalWrite(RPWMA2, LOW);

      if (maintenant - nuitTimer >= 1000) {
        stopAll();
        nuitTimer = maintenant;
        nuitState = NUIT_PAUSE_BEFORE_RETRACT;
        Serial.println("Nuit: pause before retracting...");
      }
      break;
  }
}

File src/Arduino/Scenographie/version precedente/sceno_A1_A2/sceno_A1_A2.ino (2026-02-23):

// Contrôle Actionneur - Version Complète et Directe
// Utilisation de digitalWrite pour assurer un signal fort (HIGH)
#include <SPI.h>
#include <Ethernet.h>
#include <EthernetUdp.h>
#include <OSCMessage.h>
const int RPWMA1 = 5; // Marche Avant
const int LPWMA1 = 6; // Marche Arrière
const int R_ENA1 = 7; // Enable Droite
const int L_ENA1 = 8; // Enable Gauche 2
const int RPWMA2 = A1; // Marche Avant
const int LPWMA2 = A2; // Marche Arrière
const int R_ENA2 = A3; // Enable Droite
const int L_ENA2 = A4; // Enable Gauche

byte mac[] = { 0x02, 0x00, 0x00, 0x00, 0x00, 0x01 };
IPAddress ip(10, 0, 2, 228);
EthernetUDP Udp;
const unsigned int localPort = 1111;
int pause = 500;
enum MouvementState {
  AVANT,
  PAUSE1,
  ARRIERE,
  PAUSE2
};

// ----- MODE NUIT -----
bool modeNuit = false;
unsigned long lastOSCReception = 0;
const unsigned long timeoutNuit = 10000; // 10 secondes sans message

enum NuitState {
  NUIT_SORT,
  NUIT_ENTER
};

MouvementState mouvementState = AVANT;
unsigned long mouvementTimer = 0;

NuitState nuitState = NUIT_SORT;
unsigned long nuitTimer = 0;


void setup() {
  Serial.begin(9600); // Pour le débogage sur l'écran PC

  pinMode(RPWMA1, OUTPUT);
  pinMode(LPWMA1, OUTPUT);
  pinMode(R_ENA1, OUTPUT);
  pinMode(L_ENA1, OUTPUT);
  pinMode(RPWMA2, OUTPUT);
  pinMode(LPWMA2, OUTPUT);
  pinMode(R_ENA2, OUTPUT);
  pinMode(L_ENA2, OUTPUT);
 
  // ÉTAPE CRUCIALE : On active le module (Enable)
  // Sans ça, le moteur ne recevra jamais de courant
  digitalWrite(R_ENA1, HIGH);
  digitalWrite(L_ENA1, HIGH);

  digitalWrite(R_ENA2, HIGH);
  digitalWrite(L_ENA2, HIGH);

  // Remise a la position neutre

  digitalWrite(LPWMA1, LOW);
  digitalWrite(RPWMA1, HIGH);
  digitalWrite(LPWMA2, LOW);
  digitalWrite(RPWMA2, HIGH);
  delay(5000);
  //println("position_neutre");
 
  // On s'assure que tout est à l'arrêt au début
  digitalWrite(RPWMA1, LOW);
  digitalWrite(LPWMA1, LOW);
  

  digitalWrite(RPWMA2, LOW);
  digitalWrite(LPWMA2, LOW);

  Ethernet.begin(mac, ip);
  Udp.begin(localPort);
  
  //mouvementTimer = millis();
  Serial.println("Mouvement: ENTRER >>>");
}
 
void loop() {

  checkOSCMessages();

  if (modeNuit) {
  mouvementNuit();
  } else {
  mouvement();
  }
}

void checkOSCMessages() {  
    OSCMessage msg;

    int size = Udp.parsePacket();
   // Serial.println(size);

    if (size > 0) { 
      lastOSCReception = millis();   // ← IMPORTANT
      modeNuit = false;              // on quitte le mode nuit
      while (size--) { 
        msg.fill(Udp.read());
      }

      if (msg.getInt(0) == 0) {
        pause = 50;
      }

      else if (msg.getInt(0) == 1) {
        pause = 1000;
      }

      else if (msg.getInt(0) == 2) {
        pause = 2500;
      }

      msg.empty();
      
    }
    // Activation automatique du mode nuit
    if (millis() - lastOSCReception > timeoutNuit) {
     modeNuit = true;
    }
    //Serial.println("out");
  }
  
void mouvementNuit() {

  unsigned long maintenant = millis();

  switch (nuitState) {

    case NUIT_SORT:   // SORTIR 0.5 sec
      digitalWrite(RPWMA1, LOW);
      digitalWrite(LPWMA1, HIGH);

      digitalWrite(RPWMA2, LOW);
      digitalWrite(LPWMA2, HIGH);

      if (maintenant - nuitTimer >= 500) {
        digitalWrite(LPWMA1, LOW);
        digitalWrite(LPWMA2, LOW);
        nuitTimer = maintenant;
        nuitState = NUIT_ENTER;
      }
      break;

    case NUIT_ENTER:  // ENTRER 1 sec
      digitalWrite(LPWMA1, LOW);
      digitalWrite(RPWMA1, HIGH);

      digitalWrite(LPWMA2, LOW);
      digitalWrite(RPWMA2, HIGH);

      if (maintenant - nuitTimer >= 1000) {
        digitalWrite(RPWMA1, LOW);
        digitalWrite(RPWMA2, LOW);
        nuitTimer = maintenant;
        nuitState = NUIT_SORT;
      }
      break;
  }
}

void mouvement() {
  
  unsigned long maintenant = millis();

  switch (mouvementState) {
    case AVANT:

      digitalWrite(LPWMA1, LOW);
      digitalWrite(RPWMA1, HIGH);
      digitalWrite(LPWMA2, LOW);
      digitalWrite(RPWMA2, HIGH);

      if (maintenant - mouvementTimer >= 1500) {
        
        digitalWrite(RPWMA1, LOW);   // stop
        digitalWrite(RPWMA2, LOW);
        mouvementTimer = maintenant;
        mouvementState = PAUSE1;
        Serial.println("--- PAUSE ---");

      }
      break;

    case PAUSE1:
      if (maintenant - mouvementTimer >= pause) {
        mouvementTimer = maintenant;
        mouvementState = ARRIERE;
        Serial.println("Mouvement: SORTIR <<<");
      }
      break;

    case ARRIERE:
      digitalWrite(RPWMA1, LOW);
      digitalWrite(LPWMA1, HIGH);

      digitalWrite(RPWMA2, LOW);
      digitalWrite(LPWMA2, HIGH);

      if (maintenant - mouvementTimer >= 1000) {
        digitalWrite(LPWMA1, LOW);   // stop
        digitalWrite(LPWMA2, LOW);
        mouvementTimer = maintenant;
        mouvementState = PAUSE2;
        Serial.println("--- PAUSE ---");
      }
      break;

    case PAUSE2:
    //Serial.println("PAUSE2");
      if (maintenant - mouvementTimer >= pause) {
        mouvementTimer = maintenant;
        mouvementState = AVANT;
        Serial.println("Mouvement: ENTRER >>>");
      }
      break;
  }
}

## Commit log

2025-10-16 Add naming conventions guide for Mycorhize project
    This document outlines the naming conventions for files in the Mycorhize project, emphasizing clarity, consistency, and project-specific vocabulary. It includes guidelines for different file types, s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
2025-10-21 schema Rhizome Fritzing
    [APA102-2020_strip.fzz, Schematics_Rhizome_21-10.fzz]
2025-10-23 Added Organic-feel + UI
    Randoms qui donnent un feel organique, imparfait et conscient
    UI pour améliorer le UX de la patch
2025-10-28 Switch from 4 nodes per level to 3/level
2025-10-29 need to figure out le transfert et la récolte énergétique et leurs impacts
2025-11-07 prototype LED 4 nov
2025-11-14 gros push pour la communication serial et la gestion d'energie du rhizome
2025-11-14 added Liste de Matériel pour Tests
2025-11-15 new backend, scalable -- not readt
    Recharge des rz-rz plus graduel, états, triggers à faire.
    Working : node filling, auto-charge des rz
2025-11-18 Animations LEDs
    17 Novembre 2025
2025-11-18 Gros push pour le rhizome, integration animations led, connexion rhizome et noeud et debut menage
2025-11-18 first led anim
2025-11-18 Create RhizomePrevisualisationV2.1.blend
    rhizz
    [RhizomePrevisualisationV2.1.blend]
2025-11-21 added lidar to td
2025-11-21 script pour LiDAR
2025-11-21 16 millions de triangles en moins...
    [Champignon.obj]
2025-11-21 ajout d'une version incomplète du tox des lichens
2025-11-22 led maj she needs some love but im getting there
2025-11-22 ajout palette de couleur
2025-11-22 Schema electro v2
    [2020footprintforshare.fzz, CUSTOM_PCB.kicad_pcb, CUSTOM_PCB.kicad_sch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]
2025-11-23 nouveau tox pour les lichens
    maintenant les lichens peuvent apparaitre et disparaitre! youpi
    ajout aussi d'une zone de travail (surtout pour moi)
2025-11-23 montage des lichens avec le background
2025-11-24 tests de colo
2025-11-24 Avancements Schemas + PCB
    [Rhizome_V2.fzz, Rhizome_V2_CleanBreadboard.fzz, Rhizome_V2_CleanSchematic.fzz]
2025-11-26 update PCB
    [Rhizome_V2.fzz, Rhizome_V2_crash.fzz]
2025-11-28 Revert "3 serial par connecteur not done :( but im trying okay"
    This reverts commit d1360281388c224a6b0f9aef04cbf3a855170e75.
    [main.cpp]
2025-11-28 Avancement code noeud avec ESP32-POE-ISO
    Connection se fait avec le Teensy
2025-11-28 travail sur les lichens
2025-11-29 push pour le premier PCB
2025-12-02 PCB V1 final ordered
    [Rhizome_V2_AvecSpeaker.fzz, Rhizome_V2_NOSpeaker.fzz, Rhizome_V2_crash.fzz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]
2025-12-03 basse noeud
    [basse- Copie6.stl]
2025-12-03 tentative de régler le serial
2025-12-03 V1 de la communication inter Rhyzome
2025-12-04 Modèle 3D Rhizome V1
    [Connecteur.stl, Middle.stl, Rhyzome_femelle.stl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]
2025-12-05 slim Rhizz done
    [SlimRhizz.kicad_pcb, SlimRhizz.kicad_sch, Teensy_4.0r0.step]
2025-12-05 Modele pour case EPS32-POE-ISO
    [CasePourESP32-POE-ISO.3mf]
2025-12-06 on a les états, la respiration, les totaux, les sous-totaux
2025-12-06 stoopid teenzy plz just talk to me
    [CasePourESP32-POE-ISO.3mf]
2025-12-07 if im not fixing this tonight im crashing out <3
    [main.cpp]
2025-12-07 tentative de generation avec plus de 2 rhizomes
2025-12-07 Update model
    [Connecteur_Noeud.stl, Connecteur_rhyzome_v2.stl, Female_plug_RHYZOMME_v2.stl]
2025-12-09 mes lichens pour la générale
2025-12-09 Création de branche et ajout de changements
    blablabla
2025-12-11 fix intégration de la faille
2026-01-08 Update PCB SlimRhizz
    [SlimRhizz.kicad_pcb]
2026-01-13 Outils Organisation
    [Organisation des Résidences.xlsx]
2026-01-13 PCB Trace Width Fix
    [SlimRhizz.kicad_pcb]
2026-01-15 pcb v2
    [SlimRhizz-B_Cu.gbr, SlimRhizz-B_Mask.gbr, SlimRhizz-B_Paste.gbr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]
2026-01-18 DOUBLE UART CHECKED
2026-01-20 debut animation led
2026-01-22 update led noeud
2026-01-22 3d case 4 esp
    [espbonsens.3mf]
2026-01-22 32 stuff 4 esp
    [din_rail_spring_with_slot.stl, espbonsens.3mf, espbonsens.stl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]
2026-01-27 amelioration led tentative connexion noeud
2026-01-27 3d model conecct
    [BAse_noeu.stl, Connecteur_noeu.stl, MIDDLE_Connecteur_noeud_v2.stl]
2026-01-28 more work (it never stop)
    [4espcase.blend, DIN_holder.stl, din_rail_spring_with_slot.stl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]
2026-01-28 Sasha tu fait chier mes led :((
2026-01-28 changed DATA tox for adding Node LEDs
2026-02-02 anim led (work in progress)
2026-02-04 more led
2026-02-05 fin journee mercredi nouveau design de code
2026-02-05 more led BLOUP
2026-02-11 LED NODE
2026-02-12 modif communication et ajout led embout
2026-02-13 module de simulation -- fallback
2026-02-14 finalisation communication, led pour generale
2026-02-16 Update son 15 Fevrier
    - fixed bug switch states saturation
2026-02-23 generale went well, still some soldering issues
2026-02-27 separation LEDS
2026-02-28 led separation
2026-03-02 moved stuff
    [Organisation des Résidences.xlsx]
